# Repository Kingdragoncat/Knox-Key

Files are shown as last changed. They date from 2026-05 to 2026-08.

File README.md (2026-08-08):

# Knox Key

This is a custom USB-C FIDO2 security key. The repository contains the KiCad 9 hardware files (schematics, PCB layout, fab outputs) and the authenticator firmware. 

The hardware pairs an STM32L433 microcontroller with an ATECC608B secure element. The project started out as an STM32F072 design (originally named "kryptonite") but was later reworked to use the L433.

## Hardware Details
* **MCU:** STM32L433CB (LQFP-48) with an 8 MHz crystal and internal USB PHY.
* **Crypto:** ATECC608B secure element on I2C (PB6/PB7) for hardware TRNG.
* **Port:** USB Type-C running USB 2.0 full speed.
* **Feedback:** Single RGB LED. Green is success, red is error, blue/yellow indicates waiting for user presence.
* **Button:** Tactile button for user presence verification (supports single, double, and long presses).
* **Power:** USB bus-powered via a 3.3V MCP1700 LDO.
* **PCB:** 2-layer layout.

## Working with KiCad
Open `Knox Key Kicad.kicad_pro` in KiCad 9. Make sure to run ERC and DRC before exporting manufacturing outputs. If you are hand-assembling the board, open `bom/ibom.html` in a web browser for the interactive BOM.

## Firmware
The firmware is in `firmware/knoxkey/` and implements a FIDO2 / CTAP2 authenticator. Random numbers are pulled from the ATECC608B over I2C, while credential wrapping uses software AES. User presence is verified via the hardware button.

To build the target for the STM32L433:
```bash
cd firmware/knoxkey
cmake -B build/stm32l433-release -S . --preset default -DBUILD_TARGET=stm32l433
cmake --build build/stm32l433-release -j 8
```
Binaries (`.elf`, `.hex`, `.bin`) will compile into `build/stm32l433-release/targets/stm32l433/`. Flash them using an ST-Link or via USB DFU mode.

## Bill of Materials
17 line items, 29 components total. Machine-readable versions: [`BOM.csv`](BOM.csv) and [`BOM.md`](BOM.md). `manufacturing/bom.csv` has the same data in the exact format JLCPCB's assembly service expects.

| Designator | Qty | Value | Footprint | Description | LCSC Part # |
|---|---|---|---|---|---|
| C1, C11, C12 | 3 | 10u | 0603 | Bulk/decoupling capacitor | [C466781](https://www.lcsc.com/product-detail/C466781.html) |
| C10, C2, C3, C4, C5, C6, C7 | 7 | 100n | 0402 | Decoupling capacitor | [C6119799](https://www.lcsc.com/product-detail/C6119799.html) |
| C8, C9 | 2 | 33p | 0402 | Crystal load capacitor | [C696910](https://www.lcsc.com/product-detail/C696910.html) |
| D1 | 1 | ASMB-MTB1-0A3A2 | LED_Avago_PLCC4_3.2x2.8mm_CW | RGB status LED | — |
| J3 | 1 | Conn_01x05 | PinHeader_1x05_P2.54mm_Vertical | SWD debug header | — |
| P1 | 1 | USB_C_Plug_USB2.0 | TYPE-C-31-G-01 | USB Type-C receptacle | [C530605](https://www.lcsc.com/product-detail/C530605.html) |
| R1, R5 | 2 | 10k | 0402 | Pull-up resistor | [C60490](https://www.lcsc.com/product-detail/C60490.html) |
| R2, R3, R4 | 3 | 4k7 | 0402 | USB CC pull-down / series resistor | [C25940](https://www.lcsc.com/product-detail/C25940.html) |
| R6 | 1 | R* | 0402 | RGB LED red channel current-limiting resistor | — |
| R7 | 1 | G* | 0402 | RGB LED green channel current-limiting resistor | — |
| R8 | 1 | B* | 0402 | RGB LED blue channel current-limiting resistor | — |
| SW1 | 1 | SW_Push | SW_Push_1P1T_XKB_TS-1187A | User presence tactile button | [C318884](https://www.lcsc.com/product-detail/C318884.html) |
| U2 | 1 | ATECC608B-MAHDA | DFN-8-1EP_3x2mm_P0.5mm_EP1.3x1.5mm | Cryptographic secure element | [C1518773](https://www.lcsc.com/product-detail/C1518773.html) |
| U3 | 1 | MCP1700x-330xxTT | SOT-23 | 3.3V LDO regulator | [C39051](https://www.lcsc.com/product-detail/C39051.html) |
| U4 | 1 | USBLC6-2SC6 | SOT-23-6 | USB D+/D- ESD protection | [C7519](https://www.lcsc.com/product-detail/C7519.html) |
| U6 | 1 | STM32L433CBTx | LQFP-48_7x7mm_P0.5mm | Main microcontroller | — |
| Y1 | 1 | 8MHz | Crystal_SMD_3225-4Pin_3.2x2.5mm | Crystal oscillator | [C720915](https://www.lcsc.com/product-detail/C720915.html) |

\* R6/R7/R8 are still labeled with placeholder values (`R`/`G`/`B`) in the schematic rather than an actual resistance — confirm before ordering a board that needs them populated.

## Manufacturing & Ordering
All files needed to manufacture the board are inside `manufacturing/`:
* `gerbers/` and `knox-key-gerbers.zip` — Bare-board fabrication files.
* `bom.csv` — Bill of Materials (with LCSC part numbers).
* `positions.csv` — Pick-and-place component coordinates (CPL).
* `designators.csv` — Reference designator mappings.
* `netlist.ipc` — IPC-D-356 netlist.

For JLCPCB: Upload `knox-key-gerbers.zip` for the PCB, and use `bom.csv` and `positions.csv` for SMT assembly. Add a solder paste stencil to your order if you plan to solder manually. Don't forget to regenerate these from KiCad if you modify the layout!

## Renders
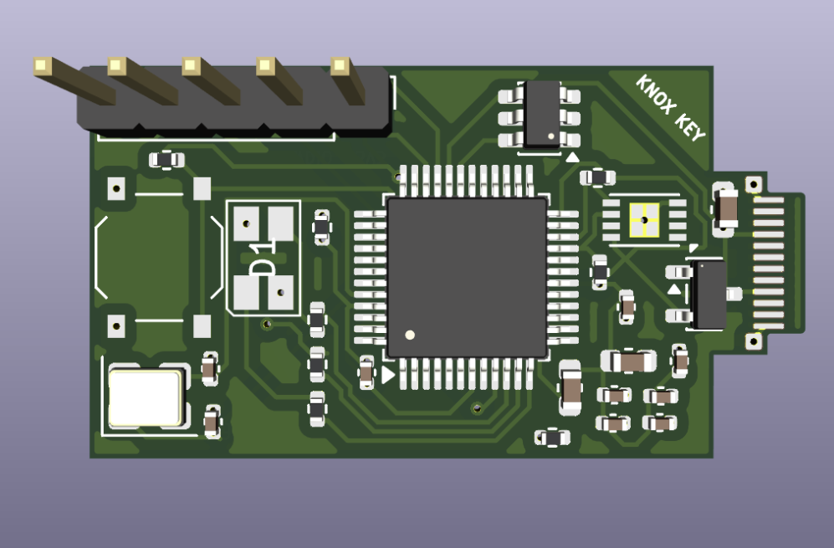
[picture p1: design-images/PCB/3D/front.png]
3D front

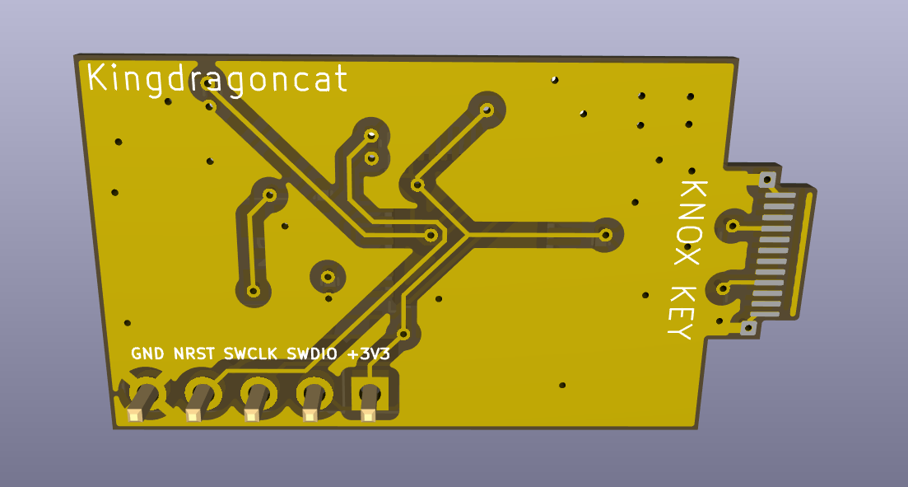
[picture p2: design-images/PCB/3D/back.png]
3D back

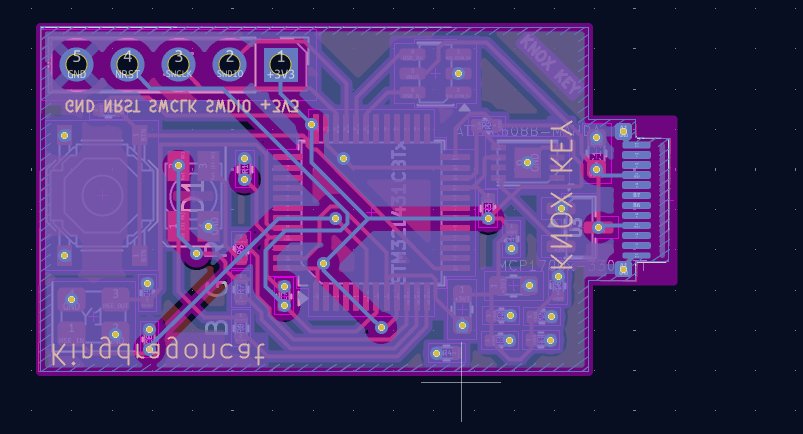
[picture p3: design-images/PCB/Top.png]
PCB layout

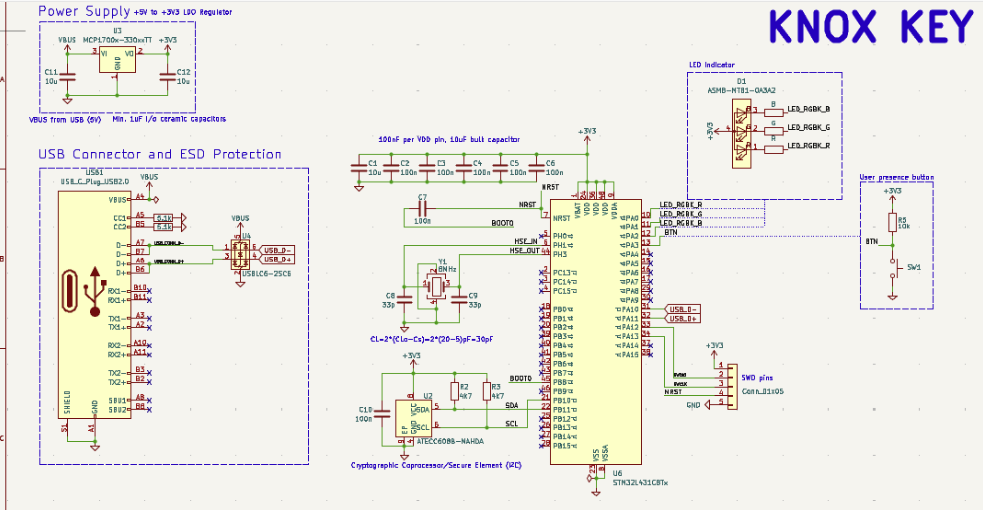
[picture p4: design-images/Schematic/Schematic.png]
Schematic


## Security Warning
This is a hobbyist project and has not undergone any formal security audit. The ATECC608B chips ship unprovisioned, meaning you must load your own keys onto the secure element. Do not use this for production environments without reviewing the firmware and provisioning process yourself.

## License
GPLv3. See `LICENSE` for details.

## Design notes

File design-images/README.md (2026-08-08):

design-images/

This folder holds two kinds of images, kept separate on purpose:

**Build journal screenshots** — flat files at the root of this folder, numbered `01`–`40` (e.g. `04_hkdf_code.png`, `21_schematic_full.png`). These are embedded chronologically in [`JOURNAL.md`](../JOURNAL.md) and shouldn't be renamed or moved; the journal links to them by exact filename.

**Current renders** — kept up to date with the latest hardware revision and embedded in the [Renders section of the README](../README.md#renders):
- `Schematic/Schematic.png` and `Schematic/schematic.pdf` — full schematic export.
- `PCB/Top.png`, `PCB/Bottom.png`, `PCB/NoFill.png`, `PCB/All.png` — 2D board layer views.
- `PCB/3D/front.png` and `PCB/3D/back.png` — 3D renders.

See [`CONTRIBUTING.md`](../CONTRIBUTING.md#how-to-update-renders) for how to regenerate the current renders after a layout change.

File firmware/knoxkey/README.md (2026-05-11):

# Knox Key Firmware

A high-security, hardware-backed FIDO2 (CTAP2) firmware implementation designed specifically for the Knox Key hardware.

## Features

- **Hardware-Backed Entropy**: All secure random numbers are generated using the onboard ATECC608B TRNG via I2C, meeting stringent security and FIPS compliance standards.
- **Hybrid Cryptography**: Leverages CryptoAuthLib for hardware random number generation while utilizing highly optimized software routines for ECDSA and AES-256 (for CTAP credential storage).
- **Advanced User Presence**: Features a fully-debounced hardware button detection engine supporting Single, Double, and Long clicks for various authentication actions.
- **Visual Feedback**: RGB LED states provide clear feedback on the authenticator's status:
  - **White Wink**: Device locator / ping
  - **Green**: Success / Validated Presence
  - **Red**: Error / Timeout / Cancelled
  - **Blue/Yellow**: Awaiting User Presence Heartbeat
- **Platform**: Ported to run efficiently on the STM32L433 MCU using TinyUSB for communication.

## Building the Firmware

### Requirements
- **CMake** (v3.20+)
- **Arm GNU Toolchain** (`arm-none-eabi-gcc`)
- **Make** / **Ninja** (depending on your OS)

### Instructions

1. **Clone the Repository**
   Make sure to clone with submodules to include all dependencies:
   ```bash
   git clone --recurse-submodules https://github.com/Kingdragoncat/Knox-Key.git
   cd "Knox-Key/Knox Key Kicad/firmware/knoxkey"
   ```

2. **Configure the Build System**
   ```bash
   cmake -B build/stm32l433-release -S . --preset default -DBUILD_TARGET=stm32l433
   ```

3. **Compile the Firmware**
   ```bash
   cmake --build build/stm32l433-release -j 8
   ```

4. **Flash the Microcontroller**
   The final compiled binaries (`.elf`, `.hex`, and `.bin`) will be output to:
   `build/stm32l433-release/targets/stm32l433/`
   
   You can flash the `.hex` or `.bin` file to your Knox Key via STM32CubeProgrammer over USB DFU mode, or using an ST-Link via SWD.

## Development & Porting

This firmware is a heavy modification of the original LionKey CTAP core. It has been extensively refactored to support the hardware components unique to the Knox Key design:
- STM32L433 target integration (USB, I2C, Flash Storage mapping)
- Replaced the software pseudo-random number generator with the ATECC608B hardware interface via `CryptoAuthLib`.
- Overhauled user-presence loops to leverage hardware interrupt-driven RGB LED multiplexing.

## License

This project is licensed under the GNU General Public License v3.0.

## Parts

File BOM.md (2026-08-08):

# Bill of Materials — Knox Key

17 line items, 29 components total. Machine-readable version: [`BOM.csv`](BOM.csv). This is also mirrored in `manufacturing/bom.csv`, which is the exact file used for JLCPCB SMT assembly ordering (see [Manufacturing & Ordering](README.md#manufacturing--ordering) in the README).

| Designator | Qty | Value | Footprint | Description | LCSC Part # |
|---|---|---|---|---|---|
| C1, C11, C12 | 3 | 10u | 0603 | Bulk/decoupling capacitor | [C466781](https://www.lcsc.com/product-detail/C466781.html) |
| C10, C2, C3, C4, C5, C6, C7 | 7 | 100n | 0402 | Decoupling capacitor | [C6119799](https://www.lcsc.com/product-detail/C6119799.html) |
| C8, C9 | 2 | 33p | 0402 | Crystal load capacitor | [C696910](https://www.lcsc.com/product-detail/C696910.html) |
| D1 | 1 | ASMB-MTB1-0A3A2 | LED_Avago_PLCC4_3.2x2.8mm_CW | RGB status LED | — |
| J3 | 1 | Conn_01x05 | PinHeader_1x05_P2.54mm_Vertical | SWD debug header | — |
| P1 | 1 | USB_C_Plug_USB2.0 | TYPE-C-31-G-01 | USB Type-C receptacle | [C530605](https://www.lcsc.com/product-detail/C530605.html) |
| R1, R5 | 2 | 10k | 0402 | Pull-up resistor | [C60490](https://www.lcsc.com/product-detail/C60490.html) |
| R2, R3, R4 | 3 | 4k7 | 0402 | USB CC pull-down / series resistor | [C25940](https://www.lcsc.com/product-detail/C25940.html) |
| R6 | 1 | R* | 0402 | RGB LED red channel current-limiting resistor | — |
| R7 | 1 | G* | 0402 | RGB LED green channel current-limiting resistor | — |
| R8 | 1 | B* | 0402 | RGB LED blue channel current-limiting resistor | — |
| SW1 | 1 | SW_Push | SW_Push_1P1T_XKB_TS-1187A | User presence tactile button | [C318884](https://www.lcsc.com/product-detail/C318884.html) |
| U2 | 1 | ATECC608B-MAHDA | DFN-8-1EP_3x2mm_P0.5mm_EP1.3x1.5mm | Cryptographic secure element | [C1518773](https://www.lcsc.com/product-detail/C1518773.html) |
| U3 | 1 | MCP1700x-330xxTT | SOT-23 | 3.3V LDO regulator | [C39051](https://www.lcsc.com/product-detail/C39051.html) |
| U4 | 1 | USBLC6-2SC6 | SOT-23-6 | USB D+/D- ESD protection | [C7519](https://www.lcsc.com/product-detail/C7519.html) |
| U6 | 1 | STM32L433CBTx | LQFP-48_7x7mm_P0.5mm | Main microcontroller | — |
| Y1 | 1 | 8MHz | Crystal_SMD_3225-4Pin_3.2x2.5mm | Crystal oscillator | [C720915](https://www.lcsc.com/product-detail/C720915.html) |

\* R6/R7/R8 (the RGB LED current-limiting resistors) are still labeled with placeholder values (`R`/`G`/`B`) in the schematic rather than an actual resistance — confirm and update before ordering a board that needs them populated.

Parts without an LCSC number (D1, J3, U6) aren't in JLCPCB's basic/extended parts library under that footprint/value combo and need to be hand-placed or sourced separately.

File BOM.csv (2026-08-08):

Designator | Quantity | Value | Footprint | Description | LCSC Part #
C1, C11, C12 | 3 | 10u | 0603 | Bulk/decoupling capacitor | C466781
C10, C2, C3, C4, C5, C6, C7 | 7 | 100n | 0402 | Decoupling capacitor | C6119799
C8, C9 | 2 | 33p | 0402 | Crystal load capacitor | C696910
D1 | 1 | ASMB-MTB1-0A3A2 | LED_Avago_PLCC4_3.2x2.8mm_CW | RGB status LED
J3 | 1 | Conn_01x05 | PinHeader_1x05_P2.54mm_Vertical | SWD debug header
P1 | 1 | USB_C_Plug_USB2.0 | TYPE-C-31-G-01 | USB Type-C receptacle | C530605
R1, R5 | 2 | 10k | 0402 | Pull-up resistor | C60490
R2, R3, R4 | 3 | 4k7 | 0402 | USB CC pull-down / series resistor | C25940
R6 | 1 | R* | 0402 | RGB LED red channel current-limiting resistor
R7 | 1 | G* | 0402 | RGB LED green channel current-limiting resistor
R8 | 1 | B* | 0402 | RGB LED blue channel current-limiting resistor
SW1 | 1 | SW_Push | SW_Push_1P1T_XKB_TS-1187A | User presence tactile button | C318884
U2 | 1 | ATECC608B-MAHDA | DFN-8-1EP_3x2mm_P0.5mm_EP1.3x1.5mm | Cryptographic secure element | C1518773
U3 | 1 | MCP1700x-330xxTT | SOT-23 | 3.3V LDO regulator | C39051
U4 | 1 | USBLC6-2SC6 | SOT-23-6 | USB D+/D- ESD protection | C7519
U6 | 1 | STM32L433CBTx | LQFP-48_7x7mm_P0.5mm | Main microcontroller
Y1 | 1 | 8MHz | Crystal_SMD_3225-4Pin_3.2x2.5mm | Crystal oscillator | C720915

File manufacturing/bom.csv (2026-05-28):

Designator | Footprint | Quantity | Value | LCSC Part #
C1, C11, C12 | 0603 | 3 | 10u | C466781
C10, C2, C3, C4, C5, C6, C7 | 0402 | 7 | 100n | C6119799
C8, C9 | 0402 | 2 | 33p | C696910
D1 | LED_Avago_PLCC4_3.2x2.8mm_CW | 1 | ASMB-MTB1-0A3A2
J3 | PinHeader_1x05_P2.54mm_Vertical | 1 | Conn_01x05
P1 | TYPE-C-31-G-01 | 1 | USB_C_Plug_USB2.0 | C530605
R1, R5 | 0402 | 2 | 10k | C60490
R2, R3, R4 | 0402 | 3 | 4k7 | C25940
R6 | 0402 | 1 | R
R7 | 0402 | 1 | G
R8 | 0402 | 1 | B
SW1 | SW_Push_1P1T_XKB_TS-1187A | 1 | SW_Push | C318884
U2 | DFN-8-1EP_3x2mm_P0.5mm_EP1.3x1.5mm | 1 | ATECC608B-MAHDA | C1518773
U3 | SOT-23 | 1 | MCP1700x-330xxTT | C39051
U4 | SOT-23-6 | 1 | USBLC6-2SC6 | C7519
U6 | LQFP-48_7x7mm_P0.5mm | 1 | STM32L433CBTx
Y1 | Crystal_SMD_3225-4Pin_3.2x2.5mm | 1 | 8MHz | C720915

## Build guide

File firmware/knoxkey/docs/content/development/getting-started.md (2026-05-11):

---
sidebar_position: 1
---

# Getting Started

Set up development environment, build the sources, and run LionKey.

## Requirements

- [CMake] _(tested with version 3.30.5)_
  - Note: [CLion](#using-ide) has a bundled CMake so there is no need to install it.

- [Arm GNU Toolchain] _(tested with Version 14.2.Rel1)_
  - Download _AArch32 bare-metal target (arm-none-eabi)_ from the Arm website [here][Arm GNU Toolchain].
  - On macOS, `brew install --cask gcc-arm-embedded` can be used.

- [OpenOCD] or any other tool for programming and debugging Arm Cortex-M microcontrollers,
  such as pyOCD or ST-LINK_gdbserver (a part of STM32CubeIDE).

  :::danger[Caution]

  **STM32H5** does not work with the original OpenOCD.
  Currently, it only works with the STMicroelectronics' fork [STMicroelectronics/OpenOCD],
  which has to be built from source, **see 👉 [this guide for the instructions](./openocd)**

  :::

## Cloning the Project

The project uses [Git submodules] to manage some of the external dependencies (see [.gitmodules](https://github.com/pokusew/lionkey/blob/main/.gitmodules)).

There are two options how to get the contents of the submodules:

**When cloning the project**, you can use:

```bash
git clone --recurse-submodules https://github.com/pokusew/lionkey.git
```

**If you already cloned the project** and forgot `--recurse-submodules`, you can use:

```bash
git submodule update --init --recursive
```

## Build from the Command Line

It is possible to build, flash and start the whole project from the command line.

Building is done via `cmake` since this project is a standard [CMake] project (see [CMakeLists.txt](https://github.com/pokusew/lionkey/blob/main/CMakeLists.txt)).
We also included a [CMakePresets.json](https://github.com/pokusew/lionkey/blob/main/CMakePresets.json) to simplify passing common options.

Here is an example how to build the executable for the NUCLEO-H533RE board with the STM32H533RET6 MCU.

```bash
# configure step (only has to be done once)
cmake --preset stm32h533-debug
# build step
cmake --build --preset stm32h533-debug
```

Flashing can be done for example using `openocd` like this (run from the project root):

```bash
openocd -s /usr/local/share/openocd/scripts -f targets/stm32h533/st_nucleo_h5.cfg -c 'tcl_port disabled' -c 'gdb_port disabled' -c 'program "build/stm32h533-debug/targets/stm32h533/lionkey_stm32h533.elf"' -c reset -c shutdown
```

## Using IDE

**Use JetBrains [CLion] (free for non-commercial use) for development.**
The project is already imported and fully configured, use _File > Open..._ to just open it.

If you have all the [tools](#requirements) installed, you should be able to open, build and run the project from CLion.

You can read more in this [CLion's Embedded development with STM32CubeMX projects][CLion-Embedded-Development]
guide.

Note that CLion bundles CMake (and other tools). Those can be used outside CLion from terminal as well.
On a x64 macOS system, the CLion's `cmake` binary
is located at `/Applications/CLion.app/Contents/bin/cmake/mac/x64/bin/cmake`.
If you add the `/Applications/CLion.app/Contents/bin/cmake/mac/x64/bin/` dir to your PATH,
then you can run CLion's CMake just by typing `cmake` in your terminal.

## SVD file for the MCU

CLion and other IDEs support SVD files for describing the layout of registers for debugging.

See the [README in the tools/svd dir](https://github.com/pokusew/lionkey/blob/main/tools/svd/README.md) which lists the available SVD files you can use.

<!-- links references -->

[Thesis]: https://github.com/pokusew/fel-masters-thesis
[Thesis-PDF]: https://github.com/pokusew/fel-masters-thesis/raw/main/docs/FIDO2_USB_Security_Key.pdf
[FIDO2]: https://fidoalliance.org/specifications/
[WebAuthn]: https://w3c.github.io/webauthn/
[CTAP 2.1]: https://fidoalliance.org/specs/fido-v2.1-ps-20210615/fido-client-to-authenticator-protocol-v2.1-ps-errata-20220621.html
[TinyCBOR]: https://github.com/intel/tinycbor
[NUCLEO-H533RE]: https://www.st.com/en/evaluation-tools/nucleo-h533re.html
[STM32H533RET6]: https://www.st.com/en/microcontrollers-microprocessors/stm32h533re.html
[STM32CubeH5-GitHub]: https://github.com/STMicroelectronics/STM32CubeH5
[STM32CubeH5-Product-Page]: https://www.st.com/en/embedded-software/stm32cubeh5.html#documentation
[UM3132]: https://www.st.com/resource/en/user_manual/um3132-description-of-stm32h5-hal-and-lowlayer-drivers-stmicroelectronics.pdf
[STM32CubeMX]: https://www.st.com/en/development-tools/stm32cubemx.html
[CLion]: https://www.jetbrains.com/clion/
[CLion-Embedded-Development]: https://www.jetbrains.com/help/clion/embedded-development.html
[Arm GNU Toolchain]: https://developer.arm.com/downloads/-/arm-gnu-toolchain-downloads
[OpenOCD]: https://openocd.org/pages/getting-openocd.html
[STMicroelectronics/OpenOCD]: https://github.com/STMicroelectronics/OpenOCD
[xPack OpenOCD Releases]: https://github.com/xpack-dev-tools/openocd-xpack/releases
[CMake]: https://cmake.org/
[Git submodules]: https://git-scm.com/docs/gitsubmodules

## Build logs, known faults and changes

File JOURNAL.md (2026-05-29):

---
title: "Knox Key"
author: "Kingdragoncat"
description: "A high-security USB Type-C authentication key design built with KiCad 8, featuring the ATECC608B cryptographic authentication chip and secure firmware validation mechanisms."
created_at: "2026-03-10"
---

# March 10, 2026: Project Initiation & Hardware Security Research

I decided to build my own hardware FIDO2 security key. I started by researching how hardware security keys actually work, reading up on FIDO2, U2F standards, and comparing existing commercial devices like YubiKeys and Titan keys. I got inspired after doing a talk on security keys to build one myself.

Next, I looked at open-source FIDO2 key implementations. I did a deep dive into the Lionkey project, analyzing their schematics, component choices, and repository structure. This gave me a good reference model.

With a general design in mind, I initialized the KiCad project and began searching for MCU options. I checked JLCPCB's assembly catalog for parts with USB device stacks and sufficient RAM/Flash for cryptographic operations. I compared STM32F072, STM32L433, and similar models, ultimately choosing the STM32F072 as the main MCU due to its excellent FIDO2 support, cost, and availability.

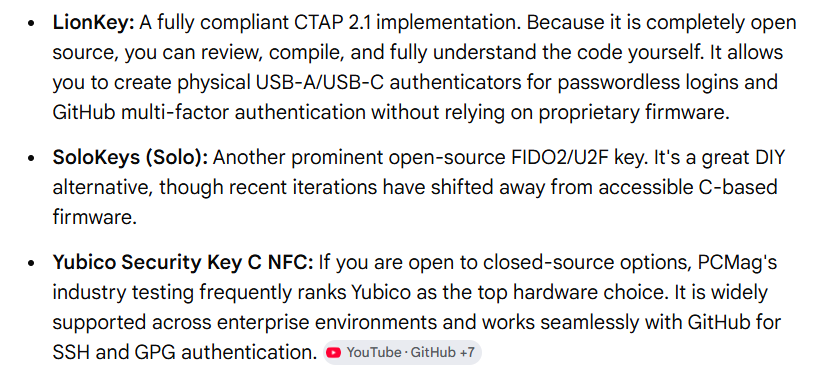
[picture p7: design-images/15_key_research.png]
Key Research

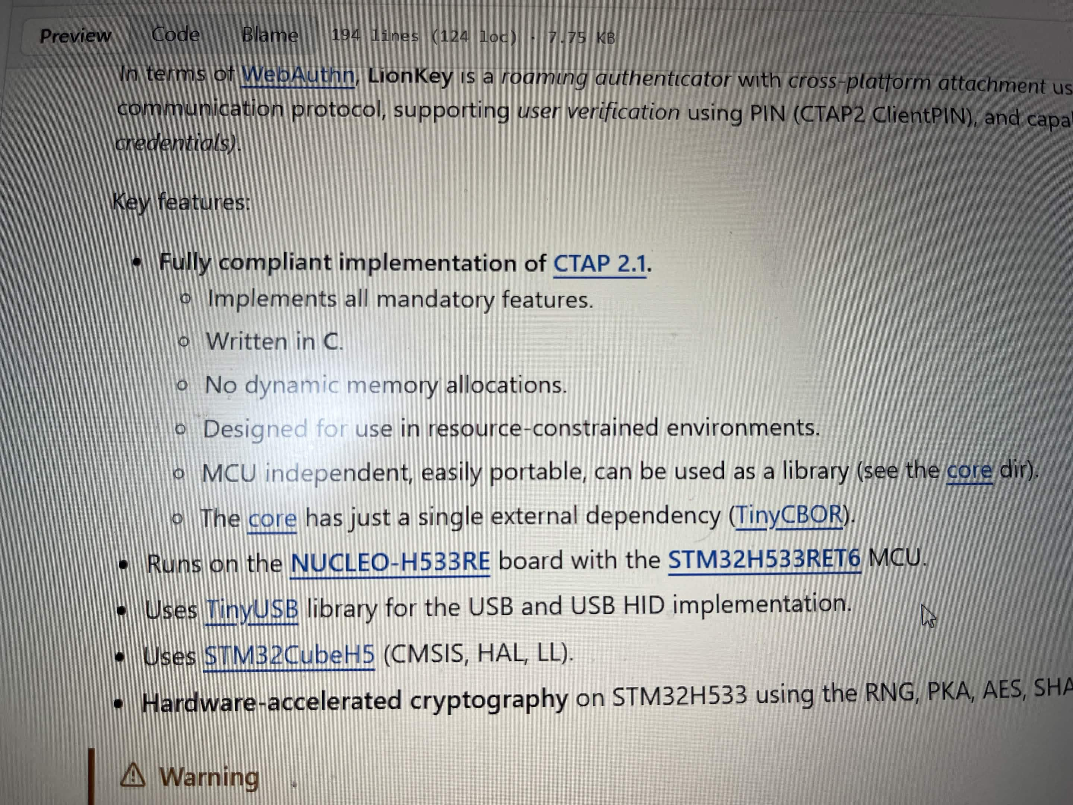
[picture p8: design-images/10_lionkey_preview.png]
LionKey reference

Start Project
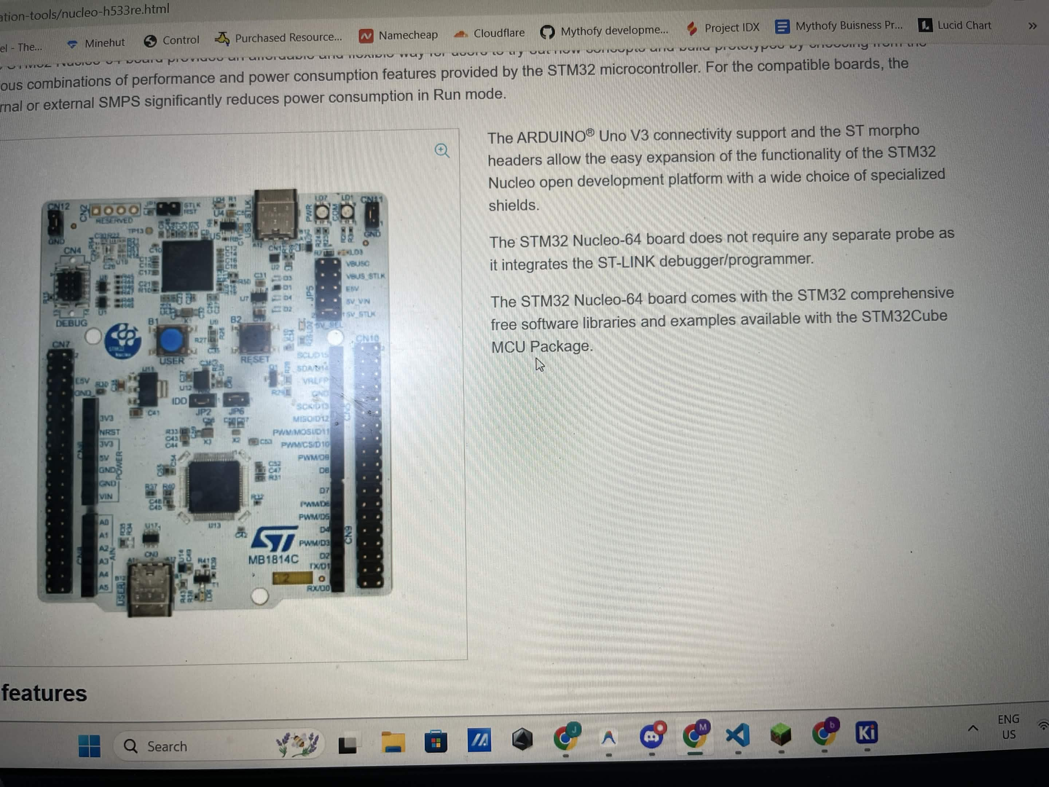
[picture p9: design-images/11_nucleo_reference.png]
Nucleo reference

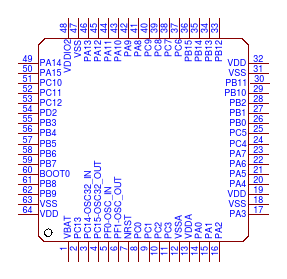
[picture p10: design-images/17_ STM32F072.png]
STM32F072 MCU


Total time spent: 3 hours

# March 12, 2026: Component Selection & BOM Generation

With the MCU selected, I focused on choosing the rest of the bill of materials. I searched JLCPCB for voltage regulators capable of producing a stable 3.3V rail from the 5V USB line, selecting the MCP1700T-3302E in a compact SOT-23 package and noting its recommended decoupling capacitor configuration.

For hardware cryptography, I picked the ATECC608 cryptographic coprocessor from Microchip. This handles ECDSA signatures and other FIDO2 operations securely. I then selected a Type-C connector and the USBLC6-2SC6 ESD protection chip for the data lines. Finally, I gathered passive component packages (resistors, decoupling capacitors, and pull-ups) to ensure everything was single-side mountable for easier assembly, and ran the KiCad BOM export plugin to generate our clean BOM file.

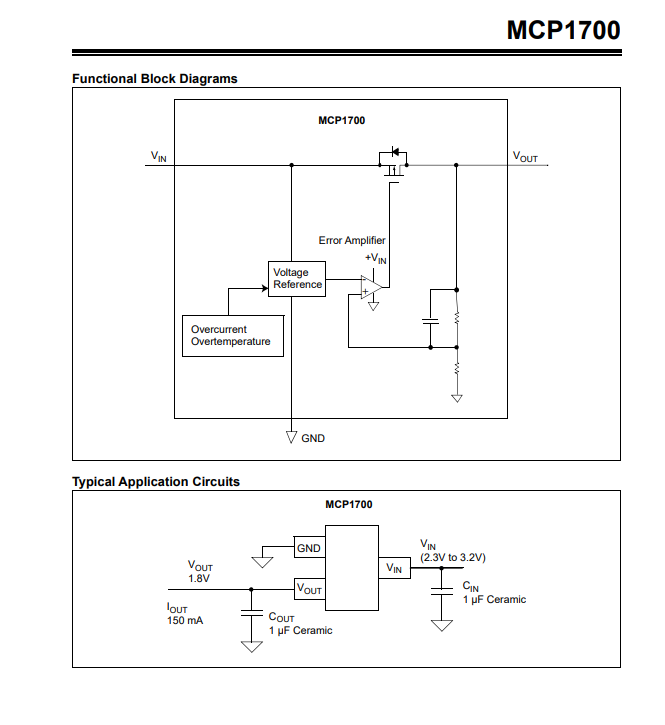
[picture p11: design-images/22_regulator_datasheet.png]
Regulator selection

ATECC608 selection
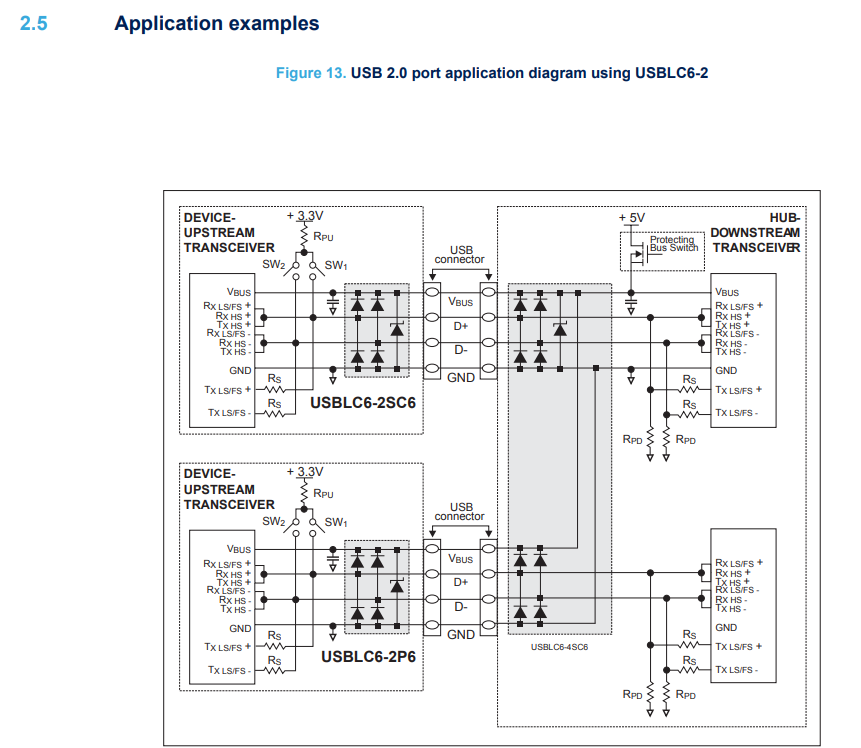
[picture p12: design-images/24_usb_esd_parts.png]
USB and ESD parts

Passives selection
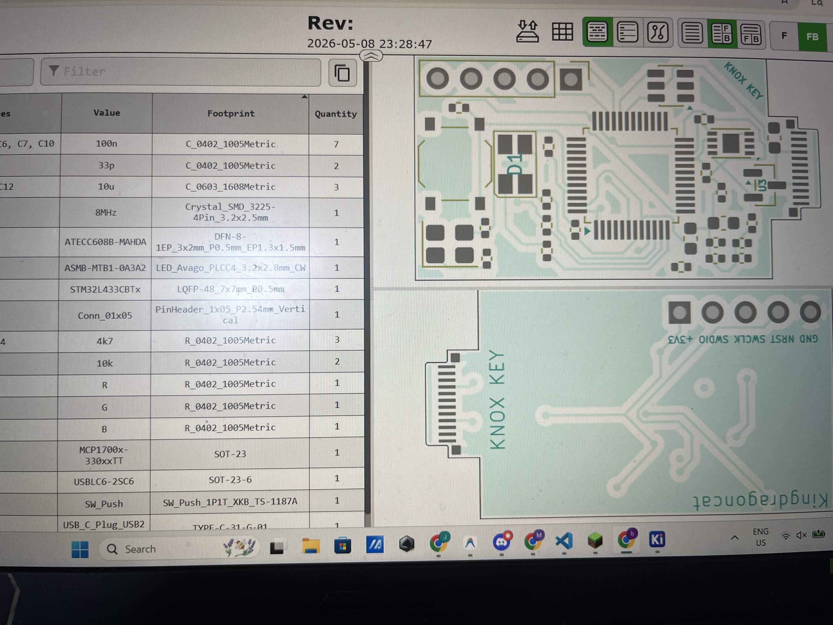
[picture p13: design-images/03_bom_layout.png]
BOM generation


Total time spent: 2 hours

# March 15, 2026: Drawing Main Power, USB, and MCU Connections

I started drafting the schematic in KiCad, beginning with the main power supply circuits. I placed the voltage regulator, its input/output decoupling capacitors, and set up the power bus.

Next, I wired up the USB Type-C connector. I configured the CC pins with 5.1k pull-down resistors to enable proper host detection, set up series impedance matching resistors on the D+/D- lines, and integrated the ESD protection chip. Finally, I added the STM32F072 microcontroller, wiring up its power pins, crystal oscillator, and local decoupling caps, making sure they were grouped logically near the MCU pins.

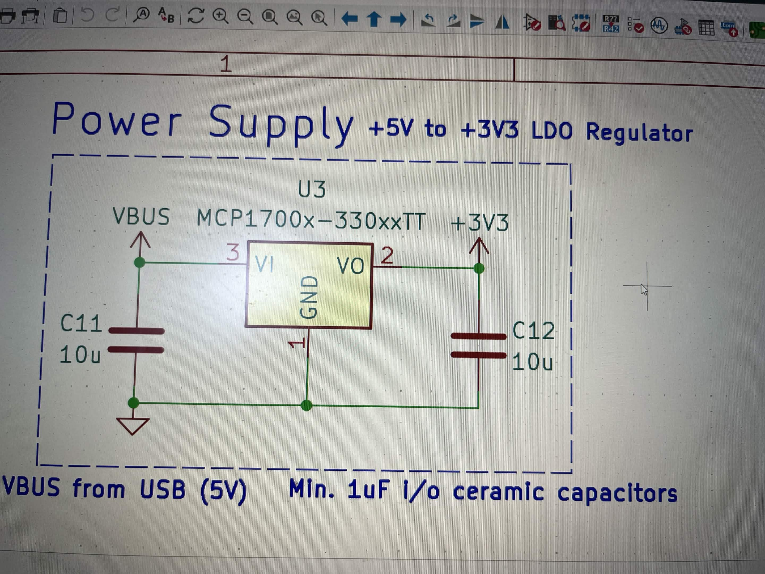
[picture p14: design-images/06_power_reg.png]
Power schematic

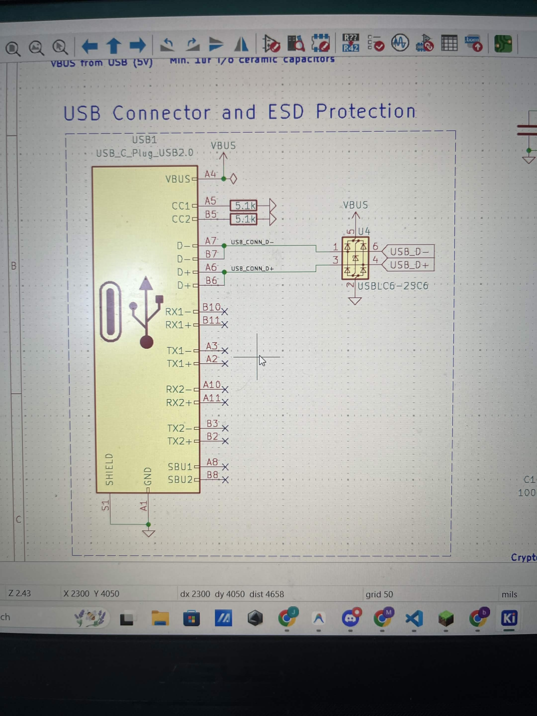
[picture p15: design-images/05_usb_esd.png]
USB ESD schematic

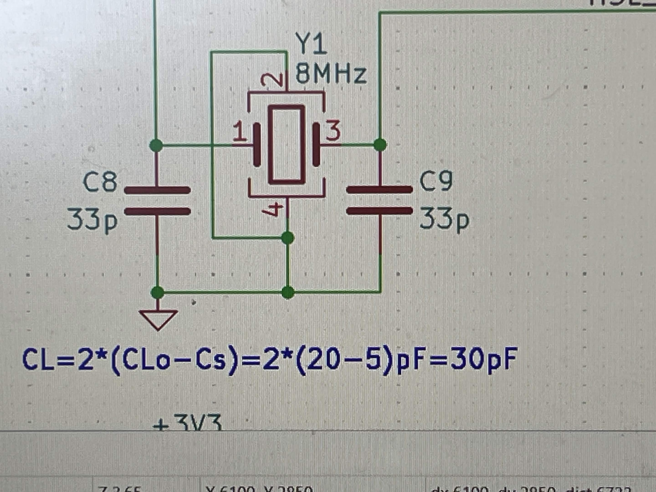
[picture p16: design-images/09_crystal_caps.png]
Crystal oscillator schematic


Total time spent: 4.5 hours

# March 18, 2026: Crypto Chip integration, Debug Ports, and ERC Checks

I completed the remaining parts of the schematic. First, I placed the ATECC608 crypto coprocessor and connected its I2C bus (SDA and SCL lines) directly to the MCU, including pull-up resistors and a dedicated decoupling capacitor.

To make testing possible, I added an SWD debug header, connecting the SWDIO and SWCLK lines. I also added a status indicator RGB LED with appropriate series current-limiting resistors, as well as a tactile button for user presence detection. Once the design was fully wired, I cleaned up the layout, routed sheet symbols, and ran the Electrical Rules Checker (ERC), correcting a couple of missing pin connections.

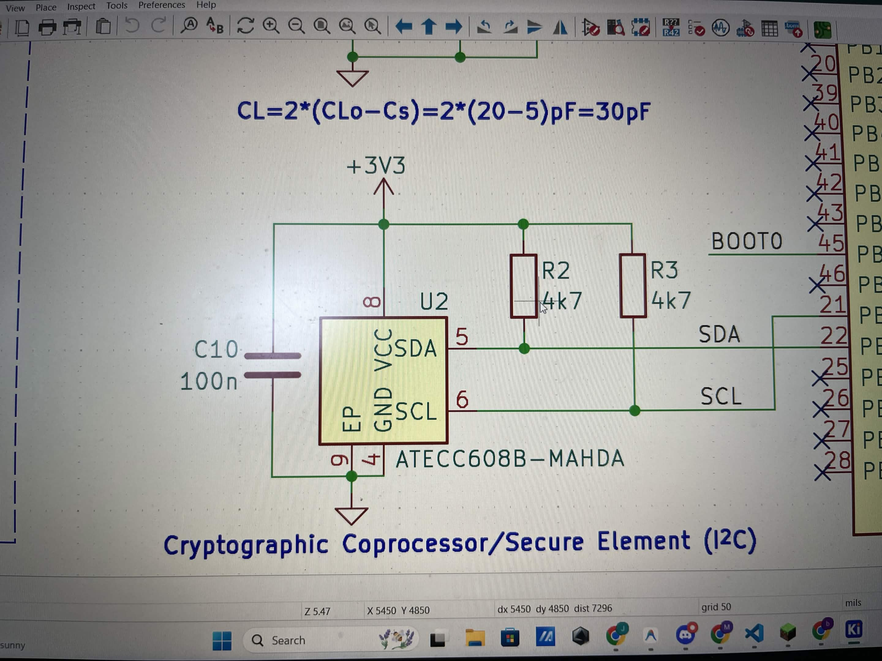
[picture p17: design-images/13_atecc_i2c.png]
ATECC608 I2C schematic

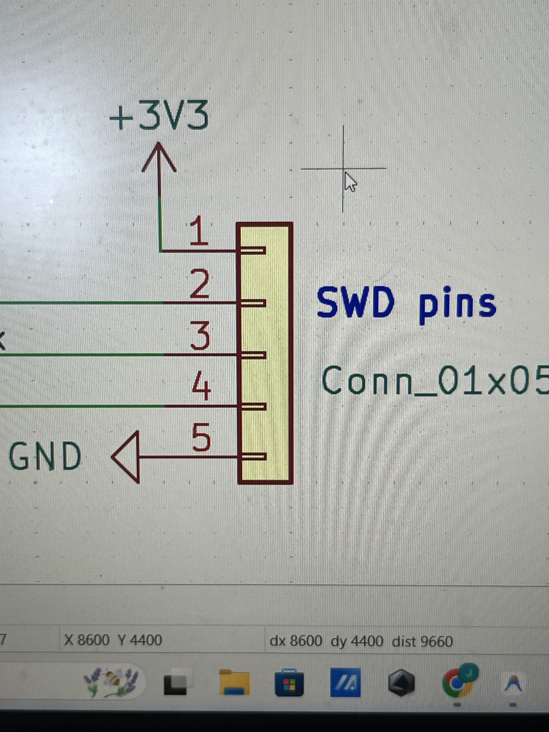
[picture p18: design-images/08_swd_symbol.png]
SWD port schematic

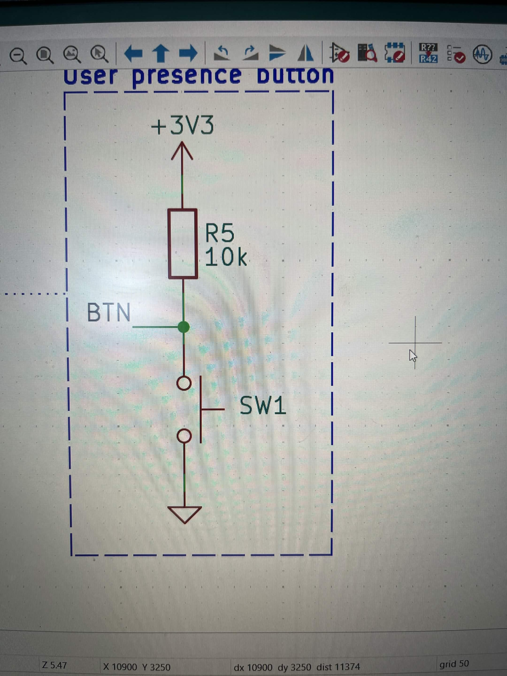
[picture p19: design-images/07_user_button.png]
User button and LED schematic

Full schematic
ERC check report

Total time spent: 2.25 hours

# March 22, 2026: PCB Placement & Critical Trace Routing

With a clean schematic, I imported the netlist into the PCB Editor. I spent a long time arranging the components to minimize the board's footprint, placing the USB Type-C connector on the edge, the MCU in the center, and the crypto chip and passives in compact clusters.

Once the layout was solid, I routed the copper traces. I prioritized the critical USB differential pair, ensuring the D+ and D- lines were routed with matched lengths and controlled impedance. I kept these high-speed lines away from noisier components and routing paths, making multiple optimization passes to keep trace lengths short.

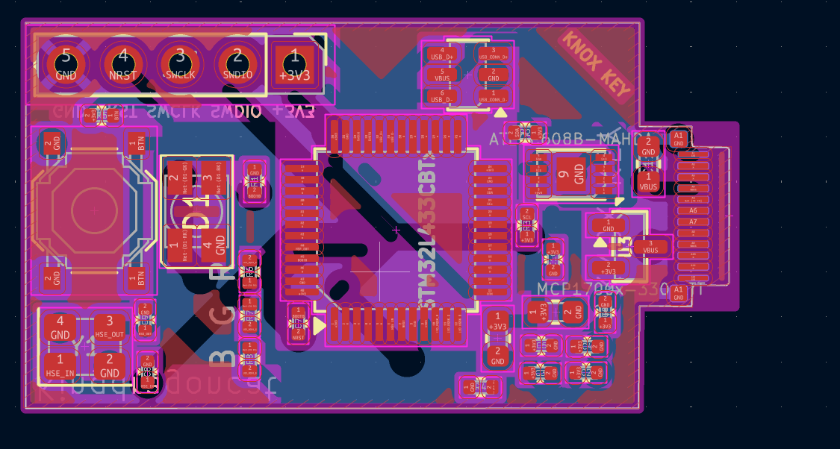
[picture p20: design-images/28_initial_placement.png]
PCB placement

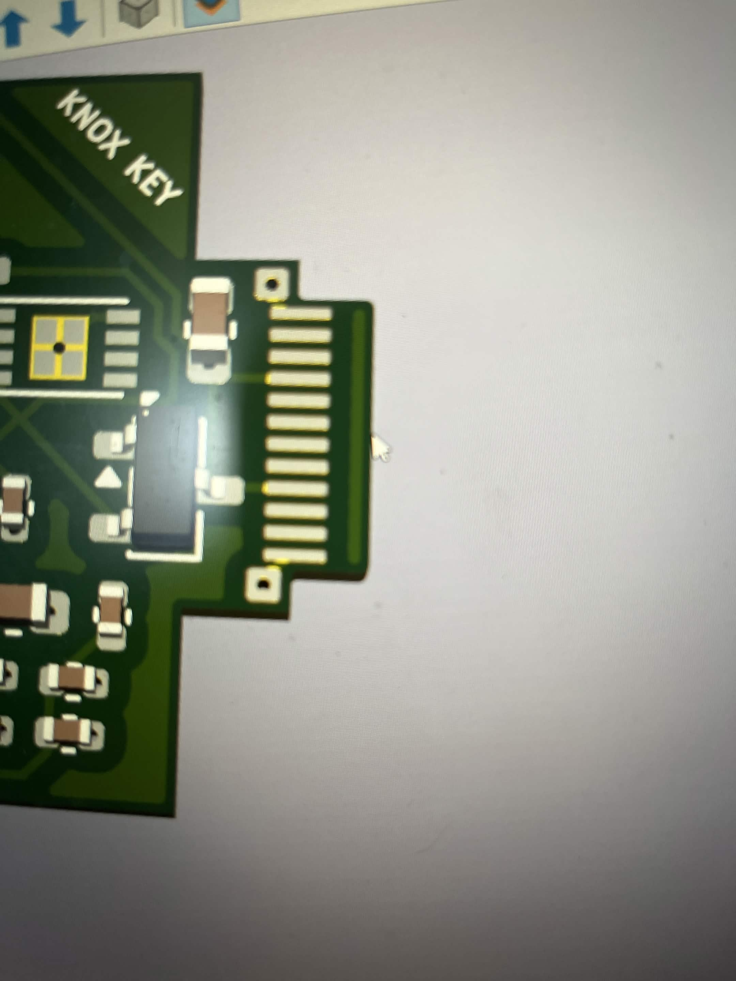
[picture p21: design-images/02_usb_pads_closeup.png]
USB trace routing


Total time spent: 6.5 hours

# March 25, 2026: Ground Pouring & Design Rule Checks

I worked on improving noise immunity and power distribution. First, I added copper ground planes to the top and bottom layers of the board, along with 3.3V power rails to distribute current cleanly. 

To improve performance, I replaced my original discrete wired ground connections with a unified ground pour/splash. Removing the old ground traces and stitching the planes together with vias took about 40 minutes. Finally, I ran the Design Rules Checker (DRC), correcting a few spacing violations and narrow trace segments.

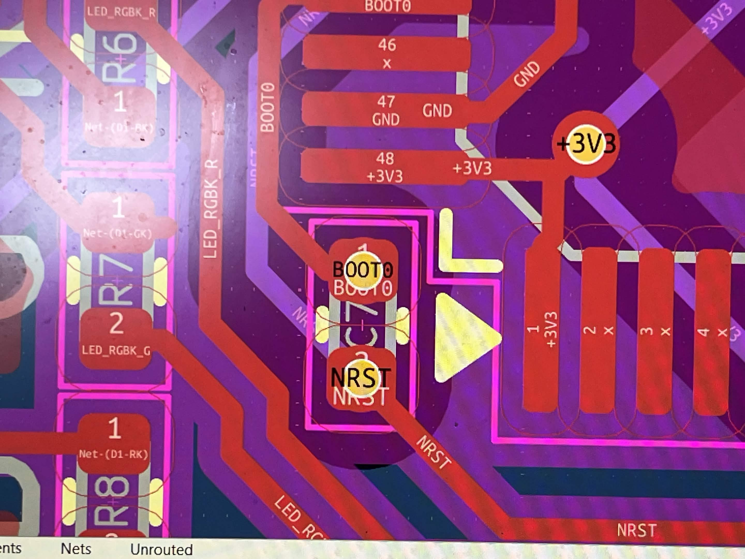
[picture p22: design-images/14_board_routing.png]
Board trace views

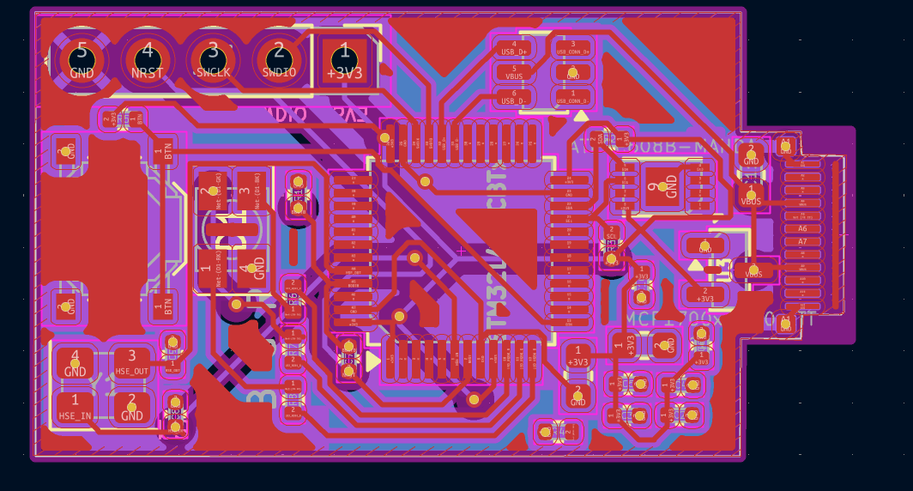
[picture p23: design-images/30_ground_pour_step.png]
Ground pour

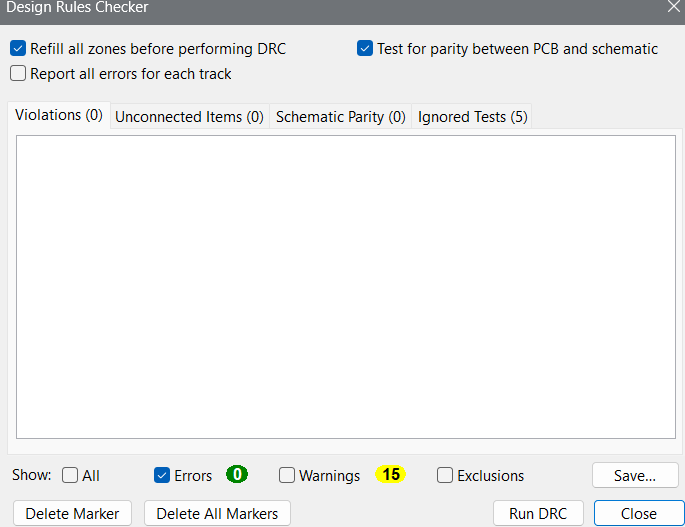
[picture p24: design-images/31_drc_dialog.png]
DRC check report


Total time spent: 3.2 hours

# March 28, 2026: Modifying USB Connector and Crash Recovery

I attempted to modify the USB Type-C connector to a more robust version with a metal shell for extra durability. This required changing the schematic symbol, switching the footprint, and rerouting the critical USB data lines. 

Halfway through the layout rework, KiCad crashed unexpectedly. I lost about 30 minutes of work because of the crash. Luckily, I was able to recover most of it from the automatic backups in my project folder. I restored the project, re-completed the PCB modifications, and fixed the DRC clearance issues again.

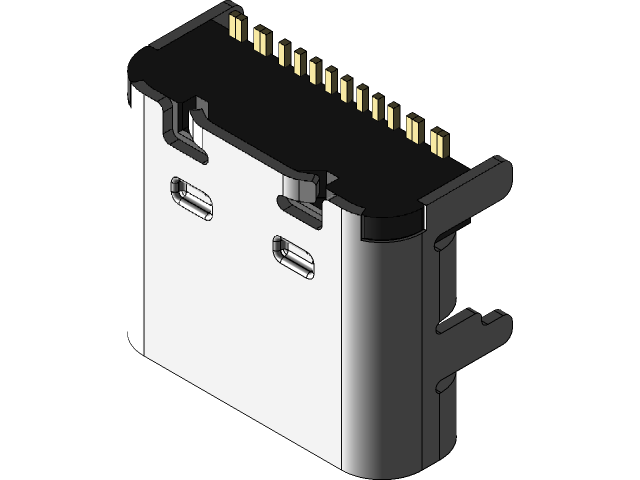
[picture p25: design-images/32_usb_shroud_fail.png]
USB footprint rework

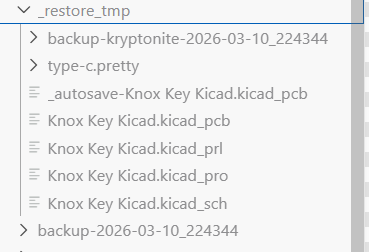
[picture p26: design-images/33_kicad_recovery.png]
KiCad recovery folder

PCB layout state

Total time spent: 4 hours

# April 02, 2026: Simplification, Slack Feedback, & Manufacturing Prep

After reviewing the complex metal-shrouded connector, I realized it added unnecessary complexity and routing congestion. I decided to revert to the original, simpler USB Type-C design. 

I posted the design on the Hack Club Slack to get feedback. Someone pointed out that the RGB LED was wired to GND instead of 3.3V, so I corrected the schematic and rerouted that section. I then exported our production-ready Gerber files, drill files, and component placement coordinates (CPL). I did a final check using the 3D viewer to make sure component clearances and alignments looked correct.

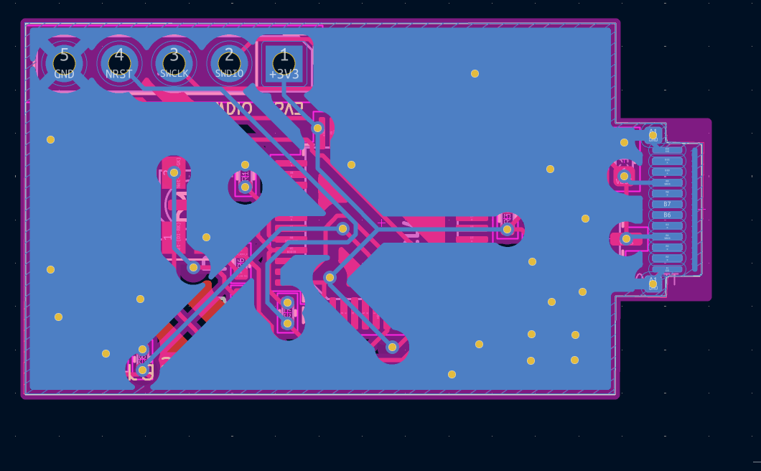
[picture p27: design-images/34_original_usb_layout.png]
Reverted USB layout

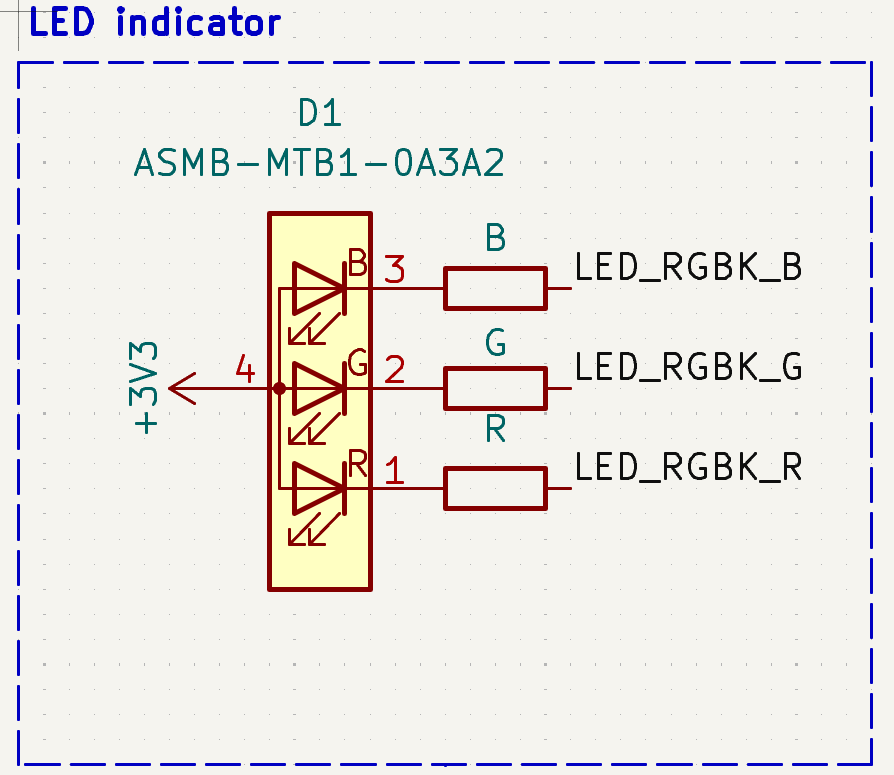
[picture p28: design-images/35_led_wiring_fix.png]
LED wiring fix

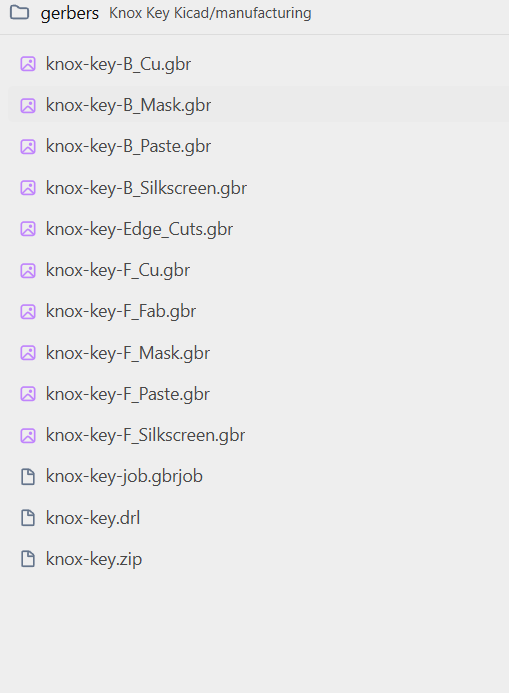
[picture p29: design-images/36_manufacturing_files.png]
Generated gerbers list

3D model check

Total time spent: 3.5 hours

# April 10, 2026: Firmware Build System & USB Setup

With the hardware finalized, I transitioned to software. I set up the firmware build environment using CMake and the `arm-none-eabi-gcc` toolchain. I configured the build settings for the ARM Cortex-M0 core and defined the compiler flags and linker script mappings.

Once the build system compiled successfully, I configured the STM32 HAL USB device stack. I defined the basic USB descriptors, set up endpoint configurations, and confirmed that the device successfully enumerated on my PC as an unrecognized USB device.

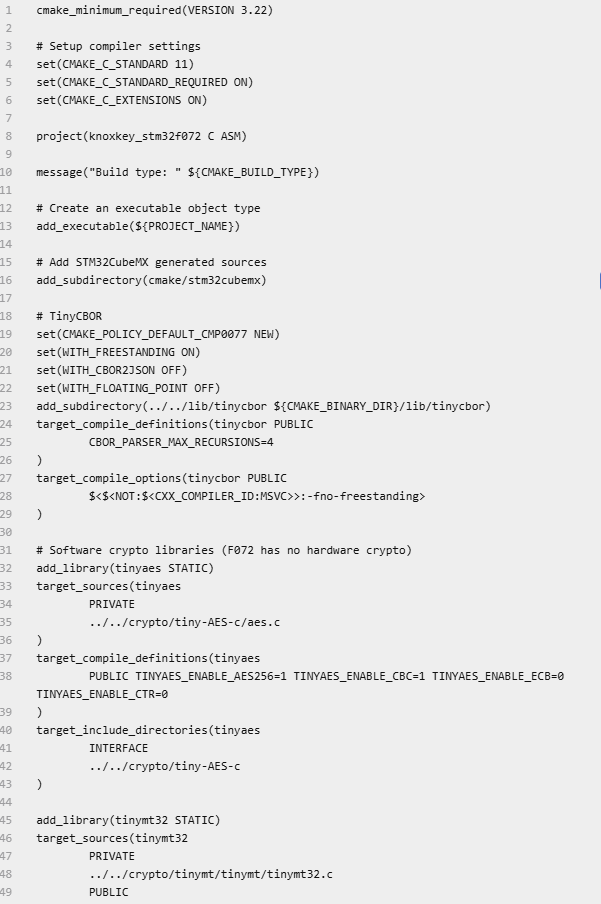
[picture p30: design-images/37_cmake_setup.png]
CMake setup

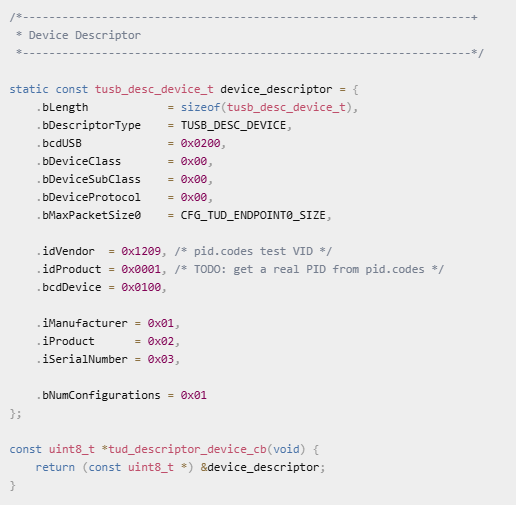
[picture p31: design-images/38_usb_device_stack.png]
USB stack setup


Total time spent: 2.5 hours

# April 15, 2026: Implementing FIDO2 & Command Parsing

I began implementing the FIDO2 protocol layer. I set up the USB Human Interface Device (HID) descriptors so the key could communicate with the host operating system. I also implemented key derivation logic utilizing HKDF for security.

Finally, I wrote the basic packet parsing state machine. This extracts incoming FIDO2 command packets from raw USB HID reports and routes them to the appropriate handler functions. The key can now parse packets and prepare response packets to send back to the computer.

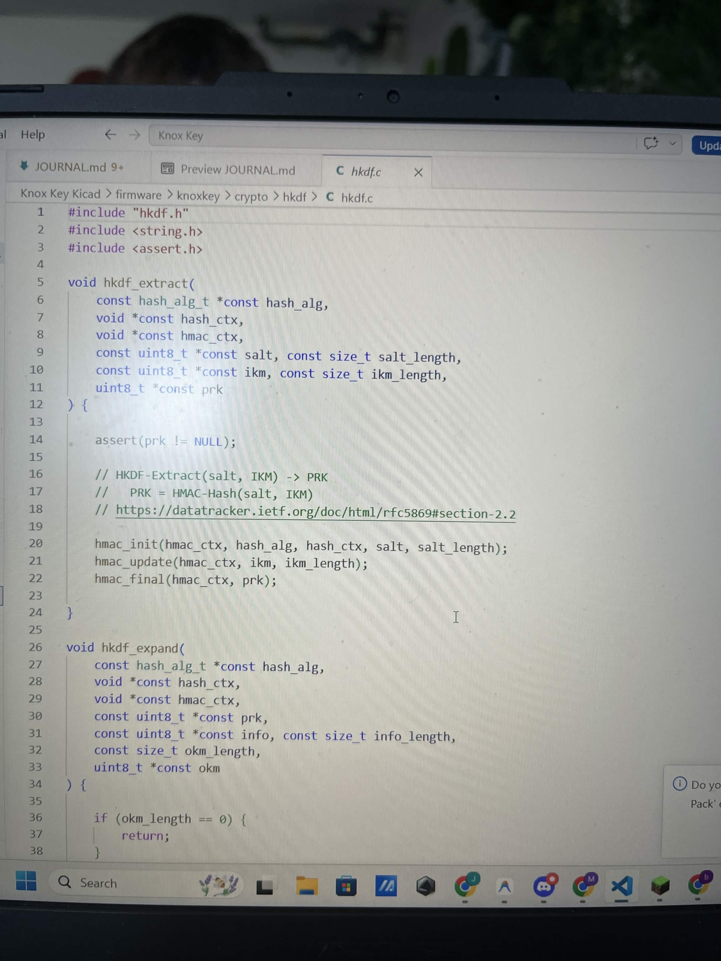
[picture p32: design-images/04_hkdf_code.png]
FIDO2 HKDF implementation

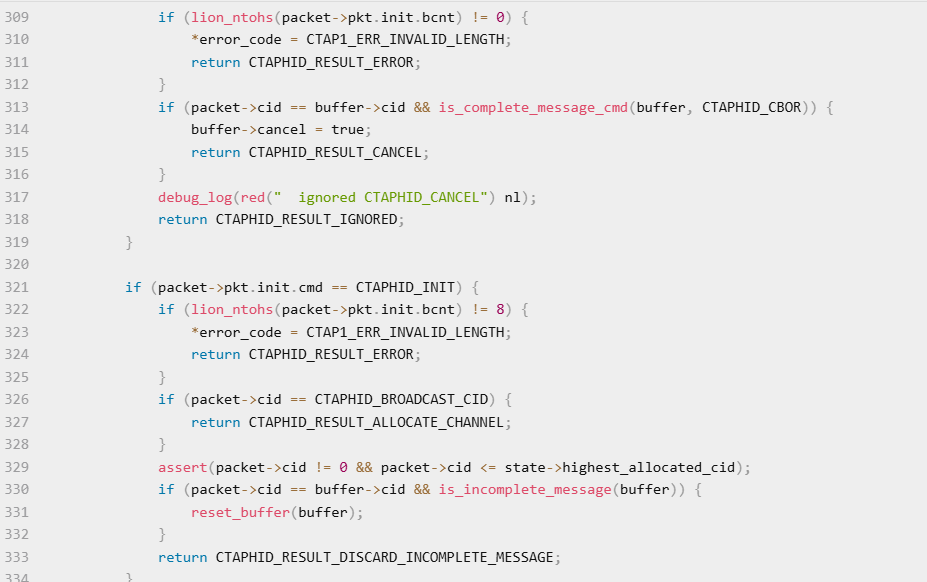
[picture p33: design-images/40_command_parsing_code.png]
Command parsing code


Total time spent: 1.25 hours

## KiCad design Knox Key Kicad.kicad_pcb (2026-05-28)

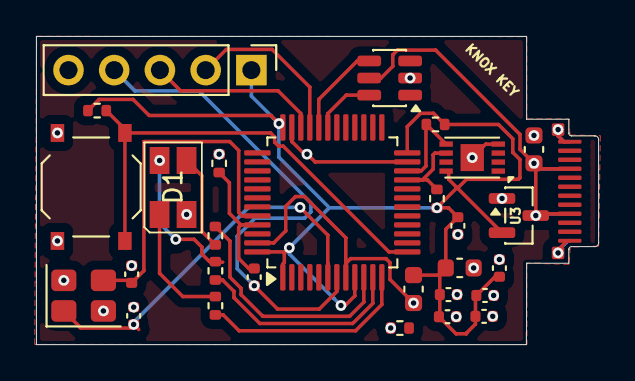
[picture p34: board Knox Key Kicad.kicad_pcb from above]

Board: 2 copper layers, 31.2 x 17.1 mm, 29 parts (0 on the bottom side), 20 nets.

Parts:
C1, C11, C12: 10u; C_0603_1608Metric
C2, C3, C4, C5, C6, C7, C10: 100n; C_0402_1005Metric
C8, C9: 33p; C_0402_1005Metric
D1: ASMB-MTB1-0A3A2; LED_Avago_PLCC4_3.2x2.8mm_CW
J3: Conn_01x05; PinHeader_1x05_P2.54mm_Vertical
P1: USB_C_Plug_USB2.0; TYPE-C-31-G-01
R1, R5: 10k; R_0402_1005Metric
R2, R3, R4: 4k7; R_0402_1005Metric
R6: R; R_0402_1005Metric
R7: G; R_0402_1005Metric
R8: B; R_0402_1005Metric
SW1: SW_Push; SW_Push_1P1T_XKB_TS-1187A
U2: ATECC608B-MAHDA; DFN-8-1EP_3x2mm_P0.5mm_EP1.3x1.5mm
U3: MCP1700x-330xxTT; SOT-23
U4: USBLC6-2SC6; SOT-23-6
U6: STM32L433CBTx; LQFP-48_7x7mm_P0.5mm
Y1: 8MHz; Crystal_SMD_3225-4Pin_3.2x2.5mm

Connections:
+3V3: C1.1, C2.1, C3.1, C4.1, C5.1, C6.1, C10.1, C12.1, J3.1, R2.1, R3.1, R5.2, U2.8 (VCC), U3.2 (VO), U6.1 (VBAT), U6.9 (VDDA), U6.24 (VDD), U6.36 (VDD), U6.48 (VDD)
/BOOT0: C7.1, R1.2, U6.45 (PB8)
/BTN: R5.1, SW1.1, U6.13 (PA3)
/HSE_IN: C8.1, U6.6 (PH1), Y1.1
/HSE_OUT: C9.1, U6.44 (PH3), Y1.3
/LED_RGBK_B: R8.2, U6.12 (PA2)
/LED_RGBK_G: R7.2, U6.11 (PA1)
/LED_RGBK_R: R6.2, U6.10 (PA0)
/NRST: C7.2, J3.4, U6.7 (NRST)
/SCL: R3.2, U2.6 (SCL), U6.21 (PB10)
/SDA: R2.2, U2.5 (SDA), U6.22 (PB11)
/SWCLK: J3.3, U6.34 (PA13)
/SWDIO: J3.2, U6.33 (PA12)
GND: C1.2, C2.2, C3.2, C4.2, C5.2, C6.2, C8.2, C9.2, C10.2, C11.2, C12.2, D1.4 (A), J3.5, P1.A1 (GND), P1.A12 (GND), P1.B1 (GND), P1.B12 (GND), R1.1, R4.1, SW1.2, U2.4 (GND), U2.9 (EP), U3.1 (GND), U4.2 (GND), U6.8 (VSSA), U6.23 (VSS), U6.35 (VSS), U6.47 (VSS), Y1.2, Y1.4
unnamed: D1.3 (BK), R6.1
unnamed: D1.2 (GK), R7.1
unnamed: D1.1 (RK), R8.1
USB_D+: U4.4 (I/O2), U6.32 (PA11)
USB_D-: U4.6 (I/O1), U6.31 (PA10)
VBUS: C11.1, P1.A4 (VBUS), P1.A9 (VBUS), P1.B4 (VBUS), P1.B9 (VBUS), U3.3 (VI), U4.5 (VBUS)

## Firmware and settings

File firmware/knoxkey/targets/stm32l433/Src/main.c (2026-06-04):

/**
 ******************************************************************************
 * @file           : main.c
 * @brief          : Main program body — Knox Key stm32l433 target
 ******************************************************************************
 *
 * Knox Key hardware:
 *   MCU:       stm32l433CBU6 (Cortex-M0, 48 MHz, 128KB flash, 16KB RAM)
 *   Crystal:   8 MHz HSE
 *   USB:       USB 2.0 Full-Speed (USB FS peripheral with integrated PHY)
 *   Security:  ATECC608B via I2C (PB6/PB7)
 *   LED:       PA0 (status LED, active high)
 *   Button:    PA1 (user presence button)
 *   LDO:      MCP1700-3.3V
 *
 ******************************************************************************
 */

#include "main.h"
#include "app.h"

/* Private variables ---------------------------------------------------------*/
volatile Button_Event CurrentButtonEvent = BUTTON_EVENT_NONE;
static uint32_t button_press_start = 0;
static uint32_t last_button_release = 0;
static uint8_t click_count = 0;
static bool button_is_pressed = false;
TIM_HandleTypeDef hTIM2;

/* Private function prototypes -----------------------------------------------*/
void SystemClock_Config(void);
static void MX_GPIO_Init(void);
static void MX_I2C1_Init(void);

int Debug_UART_Get_Byte(void) {
	return -1;
}

static Status_LED_Mode current_led_mode = STATUS_LED_MODE_OFF;
static uint32_t led_animation_start = 0;
static Status_LED_Mode previous_led_mode = STATUS_LED_MODE_OFF;

void Status_LED_Set_Mode(Status_LED_Mode mode) {
    if (mode == STATUS_LED_MODE_SUCCESS || mode == STATUS_LED_MODE_ERROR || mode == STATUS_LED_MODE_WINK) {
        if (current_led_mode != mode) {
            previous_led_mode = current_led_mode;
        }
        led_animation_start = HAL_GetTick();
    }
	current_led_mode = mode;
	if (mode == STATUS_LED_MODE_OFF) {
		HAL_GPIO_WritePin(LED_GPIO_Port, LED_R_Pin | LED_G_Pin | LED_B_Pin, GPIO_PIN_RESET);
	} else if (mode == STATUS_LED_MODE_ON) {
		HAL_GPIO_WritePin(LED_GPIO_Port, LED_R_Pin | LED_G_Pin | LED_B_Pin, GPIO_PIN_RESET);
		HAL_GPIO_WritePin(LED_GPIO_Port, LED_G_Pin, GPIO_PIN_SET); /* Solid Green */
	}
}

void Status_LED_Update(void) {
	uint32_t tick = HAL_GetTick();
	if (current_led_mode == STATUS_LED_MODE_BLINKING_NORMAL) {
		if ((tick % 1000) < 500) {
			HAL_GPIO_WritePin(LED_GPIO_Port, LED_R_Pin | LED_G_Pin, GPIO_PIN_RESET);
			HAL_GPIO_WritePin(LED_GPIO_Port, LED_B_Pin, GPIO_PIN_SET); /* Blue blink */
		} else {
			HAL_GPIO_WritePin(LED_GPIO_Port, LED_B_Pin, GPIO_PIN_RESET);
		}
	} else if (current_led_mode == STATUS_LED_MODE_BLINKING_SPECIAL) {
		if ((tick % 100) < 50) {
			HAL_GPIO_WritePin(LED_GPIO_Port, LED_B_Pin, GPIO_PIN_RESET);
			HAL_GPIO_WritePin(LED_GPIO_Port, LED_R_Pin | LED_G_Pin, GPIO_PIN_SET); /* Yellow blink */
		} else {
			HAL_GPIO_WritePin(LED_GPIO_Port, LED_R_Pin | LED_G_Pin, GPIO_PIN_RESET);
		}
	} else if (current_led_mode == STATUS_LED_MODE_SUCCESS) {
        if (tick - led_animation_start < 1000) {
            HAL_GPIO_WritePin(LED_GPIO_Port, LED_R_Pin | LED_B_Pin, GPIO_PIN_RESET);
            HAL_GPIO_WritePin(LED_GPIO_Port, LED_G_Pin, GPIO_PIN_SET); /* Solid Green */
        } else {
            Status_LED_Set_Mode(previous_led_mode);
        }
    } else if (current_led_mode == STATUS_LED_MODE_ERROR) {
        if (tick - led_animation_start < 1000) {
            HAL_GPIO_WritePin(LED_GPIO_Port, LED_G_Pin | LED_B_Pin, GPIO_PIN_RESET);
            HAL_GPIO_WritePin(LED_GPIO_Port, LED_R_Pin, GPIO_PIN_SET); /* Solid Red */
        } else {
            Status_LED_Set_Mode(previous_led_mode);
        }
    } else if (current_led_mode == STATUS_LED_MODE_WINK) {
        if (tick - led_animation_start < 2000) {
            if ((tick % 200) < 100) {
                HAL_GPIO_WritePin(LED_GPIO_Port, LED_R_Pin | LED_G_Pin | LED_B_Pin, GPIO_PIN_SET); /* White wink */
            } else {
                HAL_GPIO_WritePin(LED_GPIO_Port, LED_R_Pin | LED_G_Pin | LED_B_Pin, GPIO_PIN_RESET);
            }
        } else {
            Status_LED_Set_Mode(previous_led_mode);
        }
    }
}

int main(void) {
	HAL_Init();
	SystemClock_Config();
	MX_GPIO_Init();
	MX_I2C1_Init();

	app_run();
}

/**
 * @brief System Clock Configuration
 *        HSE 8 MHz → PLL → 48 MHz SYSCLK
 *        HSI48 → USB 48 MHz clock
 * @retval None
 */
void SystemClock_Config(void) {
	RCC_OscInitTypeDef RCC_OscInitStruct = {0};
	RCC_ClkInitTypeDef RCC_ClkInitStruct = {0};
	RCC_PeriphCLKInitTypeDef PeriphClkInit = {0};

	HAL_PWREx_ControlVoltageScaling(PWR_REGULATOR_VOLTAGE_SCALE1);

	RCC_OscInitStruct.OscillatorType = RCC_OSCILLATORTYPE_HSI48 | RCC_OSCILLATORTYPE_MSI;
	RCC_OscInitStruct.HSI48State = RCC_HSI48_ON;
	RCC_OscInitStruct.MSIState = RCC_MSI_ON;
	RCC_OscInitStruct.MSICalibrationValue = 0;
	RCC_OscInitStruct.MSIClockRange = RCC_MSIRANGE_11; /* 48 MHz */
	RCC_OscInitStruct.PLL.PLLState = RCC_PLL_NONE;
	if (HAL_RCC_OscConfig(&RCC_OscInitStruct) != HAL_OK) {
		Error_Handler();
	}

	RCC_ClkInitStruct.ClockType = RCC_CLOCKTYPE_HCLK | RCC_CLOCKTYPE_SYSCLK | RCC_CLOCKTYPE_PCLK1 | RCC_CLOCKTYPE_PCLK2;
	RCC_ClkInitStruct.SYSCLKSource = RCC_SYSCLKSOURCE_MSI;
	RCC_ClkInitStruct.AHBCLKDivider = RCC_SYSCLK_DIV1;
	RCC_ClkInitStruct.APB1CLKDivider = RCC_HCLK_DIV1;
	RCC_ClkInitStruct.APB2CLKDivider = RCC_HCLK_DIV1;
	if (HAL_RCC_ClockConfig(&RCC_ClkInitStruct, FLASH_LATENCY_2) != HAL_OK) {
		Error_Handler();
	}

	PeriphClkInit.PeriphClockSelection = RCC_PERIPHCLK_USB;
	PeriphClkInit.UsbClockSelection = RCC_USBCLKSOURCE_HSI48;
	if (HAL_RCCEx_PeriphCLKConfig(&PeriphClkInit) != HAL_OK) {
		Error_Handler();
	}
}

I2C_HandleTypeDef hi2c1;

static void MX_I2C1_Init(void) {
	hi2c1.Instance = I2C1;
	hi2c1.Init.Timing = 0x10909CEC; /* 100kHz at 48MHz SYSCLK (from CubeMX) */
	hi2c1.Init.OwnAddress1 = 0;
	hi2c1.Init.AddressingMode = I2C_ADDRESSINGMODE_7BIT;
	hi2c1.Init.DualAddressMode = I2C_DUALADDRESS_DISABLE;
	hi2c1.Init.OwnAddress2 = 0;
	hi2c1.Init.OwnAddress2Masks = I2C_OA2_NOMASK;
	hi2c1.Init.GeneralCallMode = I2C_GENERALCALL_DISABLE;
	hi2c1.Init.NoStretchMode = I2C_NOSTRETCH_DISABLE;
	if (HAL_I2C_Init(&hi2c1) != HAL_OK) {
		Error_Handler();
	}
	if (HAL_I2CEx_ConfigAnalogFilter(&hi2c1, I2C_ANALOGFILTER_ENABLE) != HAL_OK) {
		Error_Handler();
	}
	if (HAL_I2CEx_ConfigDigitalFilter(&hi2c1, 0) != HAL_OK) {
		Error_Handler();
	}
}

void HAL_I2C_MspInit(I2C_HandleTypeDef* hi2c) {
	GPIO_InitTypeDef GPIO_InitStruct = {0};
	if(hi2c->Instance==I2C1) {
		__HAL_RCC_GPIOB_CLK_ENABLE();
		/**I2C1 GPIO Configuration
		PB6     ------> I2C1_SCL
		PB7     ------> I2C1_SDA
		*/
		GPIO_InitStruct.Pin = ATECC_SCL_Pin|ATECC_SDA_Pin;
		GPIO_InitStruct.Mode = GPIO_MODE_AF_OD;
		GPIO_InitStruct.Pull = GPIO_NOPULL;
		GPIO_InitStruct.Speed = GPIO_SPEED_FREQ_VERY_HIGH;
		GPIO_InitStruct.Alternate = GPIO_AF4_I2C1;
		HAL_GPIO_Init(GPIOB, &GPIO_InitStruct);
		__HAL_RCC_I2C1_CLK_ENABLE();
	}
}

/**
 * @brief GPIO Initialization Function
 */
static void MX_GPIO_Init(void) {
	GPIO_InitTypeDef GPIO_InitStruct = {0};

	__HAL_RCC_GPIOA_CLK_ENABLE();
	__HAL_RCC_GPIOB_CLK_ENABLE();
	__HAL_RCC_GPIOH_CLK_ENABLE();

	/* LED pins */
	HAL_GPIO_WritePin(LED_GPIO_Port, LED_R_Pin | LED_G_Pin | LED_B_Pin, GPIO_PIN_RESET);
	GPIO_InitStruct.Pin = LED_R_Pin | LED_G_Pin | LED_B_Pin;
	GPIO_InitStruct.Mode = GPIO_MODE_OUTPUT_PP;
	GPIO_InitStruct.Pull = GPIO_NOPULL;
	GPIO_InitStruct.Speed = GPIO_SPEED_FREQ_LOW;
	HAL_GPIO_Init(LED_GPIO_Port, &GPIO_InitStruct);

	/* User button — PA1, external interrupt on rising edge */
	GPIO_InitStruct.Pin = USER_BTN_Pin;
	GPIO_InitStruct.Mode = GPIO_MODE_IT_RISING;
	GPIO_InitStruct.Pull = GPIO_PULLDOWN;
	HAL_GPIO_Init(USER_BTN_GPIO_Port, &GPIO_InitStruct);

	/* Enable EXTI interrupt for the button */
	HAL_NVIC_SetPriority(EXTI1_IRQn, 2, 0);
	HAL_NVIC_EnableIRQ(EXTI1_IRQn);
}

/**
 * @brief  This function is executed in case of error occurrence.
 */
void Error_Handler(void) {
	__disable_irq();
	while (1) {
	}
}

#ifdef USE_FULL_ASSERT
void assert_failed(uint8_t *file, uint32_t line) {
	(void)file;
	(void)line;
}
#endif

void Button_Update(void) {
    uint32_t tick = HAL_GetTick();
    bool raw_pressed = (HAL_GPIO_ReadPin(USER_BTN_GPIO_Port, USER_BTN_Pin) == GPIO_PIN_SET);

    if (raw_pressed && !button_is_pressed) {
        if (tick - last_button_release > 20) { // Debounce 20ms
            button_is_pressed = true;
            button_press_start = tick;
        }
    } else if (!raw_pressed && button_is_pressed) {
        if (tick - button_press_start > 20) { // Debounce 20ms
            button_is_pressed = false;
            last_button_release = tick;
            uint32_t duration = tick - button_press_start;
            
            if (duration >= 1000) {
                CurrentButtonEvent = BUTTON_EVENT_LONG_PRESS;
                click_count = 0;
            } else {
                click_count++;
            }
        }
    }

    if (!button_is_pressed && click_count > 0 && (tick - last_button_release > 300)) {
        if (click_count == 1) {
            CurrentButtonEvent = BUTTON_EVENT_SINGLE_CLICK;
        } else if (click_count >= 2) {
            CurrentButtonEvent = BUTTON_EVENT_DOUBLE_CLICK;
        }
        click_count = 0;
    }
}

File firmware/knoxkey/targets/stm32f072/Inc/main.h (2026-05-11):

/**
 ******************************************************************************
 * @file           : main.h
 * @brief          : Header for main.c file.
 *                   Knox Key STM32F072 target.
 ******************************************************************************
 */

#ifndef __MAIN_H
#define __MAIN_H

#ifdef __cplusplus
extern "C" {
#endif

/* Includes ------------------------------------------------------------------*/
#include "stm32f0xx_hal.h"
#include <stdio.h>

/* Exported types ------------------------------------------------------------*/

extern __IO uint32_t ButtonState;

#define BUTTON_RELEASED  0
#define BUTTON_PRESSED   1

/* Exported functions prototypes ---------------------------------------------*/
void Error_Handler(void);

int Debug_UART_Get_Byte(void);

typedef enum Status_LED_Mode {
	STATUS_LED_MODE_OFF = 0,
	STATUS_LED_MODE_ON = 1,
	STATUS_LED_MODE_BLINKING_NORMAL = 2,
	STATUS_LED_MODE_BLINKING_SPECIAL = 3,
} Status_LED_Mode;

void Status_LED_Set_Mode(Status_LED_Mode mode);

void HAL_TIM_MspPostInit(TIM_HandleTypeDef *htim);

/* Private defines -----------------------------------------------------------*/
/* Knox Key board pin assignments (from schematic) */

/* Status LED - PA0 (active high, optional replace with RGB) */
#define STATUS_LED_Pin        GPIO_PIN_0
#define STATUS_LED_GPIO_Port  GPIOA

/* User button - PA1 */
#define USER_BTN_Pin          GPIO_PIN_1
#define USER_BTN_GPIO_Port    GPIOA

/* ATECC608B I2C - PB6 (SCL), PB7 (SDA) */
#define ATECC_SCL_Pin         GPIO_PIN_6
#define ATECC_SCL_GPIO_Port   GPIOB
#define ATECC_SDA_Pin         GPIO_PIN_7
#define ATECC_SDA_GPIO_Port   GPIOB

/* USB D+ / D- are on PA11 / PA12 (handled by USB peripheral) */

/* SWD debug - PA13 (SWDIO), PA14 (SWCLK) */
#define SWDIO_Pin             GPIO_PIN_13
#define SWDIO_GPIO_Port       GPIOA
#define SWCLK_Pin             GPIO_PIN_14
#define SWCLK_GPIO_Port       GPIOA

#ifdef __cplusplus
}
#endif

#endif /* __MAIN_H */

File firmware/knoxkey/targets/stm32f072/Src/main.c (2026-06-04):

/**
 ******************************************************************************
 * @file           : main.c
 * @brief          : Main program body — Knox Key STM32F072 target
 ******************************************************************************
 *
 * Knox Key hardware:
 *   MCU:       STM32F072CBU6 (Cortex-M0, 48 MHz, 128KB flash, 16KB RAM)
 *   Crystal:   8 MHz HSE
 *   USB:       USB 2.0 Full-Speed (USB FS peripheral with integrated PHY)
 *   Security:  ATECC608B via I2C (PB6/PB7)
 *   LED:       PA0 (status LED, active high)
 *   Button:    PA1 (user presence button)
 *   LDO:      MCP1700-3.3V
 *
 ******************************************************************************
 */

#include "main.h"
#include "app.h"

/* Private variables ---------------------------------------------------------*/
__IO uint32_t ButtonState = BUTTON_RELEASED;
TIM_HandleTypeDef htim3;

/* Private function prototypes -----------------------------------------------*/
void SystemClock_Config(void);
static void MX_GPIO_Init(void);
static void MX_TIM3_Init(void);

/* Debug UART stub — Knox Key has no dedicated debug UART in the minimal design.
   When needed, SWO or semihosting can be used instead. */
int Debug_UART_Get_Byte(void) {
	return -1;
}

void Status_LED_Set_Mode(Status_LED_Mode mode) {
	switch (mode) {
		case STATUS_LED_MODE_OFF:
			/* Force output low */
			HAL_TIM_PWM_Stop(&htim3, TIM_CHANNEL_1);
			HAL_GPIO_WritePin(STATUS_LED_GPIO_Port, STATUS_LED_Pin, GPIO_PIN_RESET);
			break;
		case STATUS_LED_MODE_ON:
			/* Force output high */
			HAL_TIM_PWM_Stop(&htim3, TIM_CHANNEL_1);
			HAL_GPIO_WritePin(STATUS_LED_GPIO_Port, STATUS_LED_Pin, GPIO_PIN_SET);
			break;
		case STATUS_LED_MODE_BLINKING_NORMAL:
			/* ~1 Hz blink via PWM (50% duty, period = 48M / 48000 = 1000 ticks at prescaler giving 1kHz) */
			htim3.Instance->ARR = 999;
			htim3.Instance->CCR1 = 500;
			htim3.Instance->PSC = 47999; /* 48 MHz / 48000 = 1 kHz tick */
			HAL_TIM_PWM_Start(&htim3, TIM_CHANNEL_1);
			break;
		case STATUS_LED_MODE_BLINKING_SPECIAL:
			/* Fast blink ~10 Hz */
			htim3.Instance->ARR = 99;
			htim3.Instance->CCR1 = 50;
			htim3.Instance->PSC = 47999; /* 48 MHz / 48000 = 1 kHz tick */
			HAL_TIM_PWM_Start(&htim3, TIM_CHANNEL_1);
			break;
	}
}

/**
 * @brief  The application entry point.
 * @retval int
 */
int main(void) {

	HAL_Init();
	SystemClock_Config();
	MX_GPIO_Init();
	MX_TIM3_Init();

	/* app_run never returns */
	app_run();
}

/**
 * @brief System Clock Configuration
 *        HSE 8 MHz → PLL → 48 MHz SYSCLK
 *        HSI48 → USB 48 MHz clock
 * @retval None
 */
void SystemClock_Config(void) {
	RCC_OscInitTypeDef RCC_OscInitStruct = {0};
	RCC_ClkInitTypeDef RCC_ClkInitStruct = {0};
	RCC_PeriphCLKInitTypeDef PeriphClkInit = {0};

	/* Enable HSE (8 MHz crystal) and PLL (8 MHz / 1 * 6 = 48 MHz) */
	RCC_OscInitStruct.OscillatorType = RCC_OSCILLATORTYPE_HSE | RCC_OSCILLATORTYPE_HSI48;
	RCC_OscInitStruct.HSEState = RCC_HSE_ON;
	RCC_OscInitStruct.HSI48State = RCC_HSI48_ON;
	RCC_OscInitStruct.PLL.PLLState = RCC_PLL_ON;
	RCC_OscInitStruct.PLL.PLLSource = RCC_PLLSOURCE_HSE;
	RCC_OscInitStruct.PLL.PLLMUL = RCC_PLL_MUL6;
	RCC_OscInitStruct.PLL.PREDIV = RCC_PREDIV_DIV1;
	if (HAL_RCC_OscConfig(&RCC_OscInitStruct) != HAL_OK) {
		Error_Handler();
	}

	/* SYSCLK = PLLCLK = 48 MHz, HCLK = 48 MHz, PCLK1 = 48 MHz */
	RCC_ClkInitStruct.ClockType = RCC_CLOCKTYPE_HCLK | RCC_CLOCKTYPE_SYSCLK | RCC_CLOCKTYPE_PCLK1;
	RCC_ClkInitStruct.SYSCLKSource = RCC_SYSCLKSOURCE_PLLCLK;
	RCC_ClkInitStruct.AHBCLKDivider = RCC_SYSCLK_DIV1;
	RCC_ClkInitStruct.APB1CLKDivider = RCC_HCLK_DIV1;
	if (HAL_RCC_ClockConfig(&RCC_ClkInitStruct, FLASH_LATENCY_1) != HAL_OK) {
		Error_Handler();
	}

	/* USB clock from HSI48 (dedicated 48 MHz oscillator) */
	PeriphClkInit.PeriphClockSelection = RCC_PERIPHCLK_USB;
	PeriphClkInit.UsbClockSelection = RCC_USBCLKSOURCE_HSI48;
	if (HAL_RCCEx_PeriphCLKConfig(&PeriphClkInit) != HAL_OK) {
		Error_Handler();
	}
}

/**
 * @brief TIM3 Initialization Function — used for LED PWM on PA0 (TIM3_CH1)
 */
static void MX_TIM3_Init(void) {
	TIM_OC_InitTypeDef sConfigOC = {0};

	__HAL_RCC_TIM3_CLK_ENABLE();

	htim3.Instance = TIM3;
	htim3.Init.Prescaler = 47999; /* 48 MHz / 48000 = 1 kHz */
	htim3.Init.CounterMode = TIM_COUNTERMODE_UP;
	htim3.Init.Period = 999;      /* 1 kHz / 1000 = 1 Hz */
	htim3.Init.ClockDivision = TIM_CLOCKDIVISION_DIV1;
	htim3.Init.AutoReloadPreload = TIM_AUTORELOAD_PRELOAD_DISABLE;
	if (HAL_TIM_PWM_Init(&htim3) != HAL_OK) {
		Error_Handler();
	}

	sConfigOC.OCMode = TIM_OCMODE_PWM1;
	sConfigOC.Pulse = 0;
	sConfigOC.OCPolarity = TIM_OCPOLARITY_HIGH;
	sConfigOC.OCFastMode = TIM_OCFAST_DISABLE;
	if (HAL_TIM_PWM_ConfigChannel(&htim3, &sConfigOC, TIM_CHANNEL_1) != HAL_OK) {
		Error_Handler();
	}

	/* TIM3 CH1 GPIO — PA0 AF1 (TIM3_CH1) */
	HAL_TIM_MspPostInit(&htim3);
}

void HAL_TIM_MspPostInit(TIM_HandleTypeDef *htim) {
	GPIO_InitTypeDef GPIO_InitStruct = {0};
	if (htim->Instance == TIM3) {
		__HAL_RCC_GPIOA_CLK_ENABLE();
		/* PA0 — TIM3_CH1, AF1 */
		GPIO_InitStruct.Pin = STATUS_LED_Pin;
		GPIO_InitStruct.Mode = GPIO_MODE_AF_PP;
		GPIO_InitStruct.Pull = GPIO_NOPULL;
		GPIO_InitStruct.Speed = GPIO_SPEED_FREQ_LOW;
		GPIO_InitStruct.Alternate = GPIO_AF1_TIM3;
		HAL_GPIO_Init(STATUS_LED_GPIO_Port, &GPIO_InitStruct);
	}
}

/**
 * @brief GPIO Initialization Function
 */
static void MX_GPIO_Init(void) {
	GPIO_InitTypeDef GPIO_InitStruct = {0};

	__HAL_RCC_GPIOA_CLK_ENABLE();
	__HAL_RCC_GPIOB_CLK_ENABLE();
	__HAL_RCC_GPIOF_CLK_ENABLE();

	/* LED pin — start as push-pull output (will be switched to AF when PWM starts) */
	HAL_GPIO_WritePin(STATUS_LED_GPIO_Port, STATUS_LED_Pin, GPIO_PIN_RESET);
	GPIO_InitStruct.Pin = STATUS_LED_Pin;
	GPIO_InitStruct.Mode = GPIO_MODE_OUTPUT_PP;
	GPIO_InitStruct.Pull = GPIO_NOPULL;
	GPIO_InitStruct.Speed = GPIO_SPEED_FREQ_LOW;
	HAL_GPIO_Init(STATUS_LED_GPIO_Port, &GPIO_InitStruct);

	/* User button — PA1, external interrupt on rising edge */
	GPIO_InitStruct.Pin = USER_BTN_Pin;
	GPIO_InitStruct.Mode = GPIO_MODE_IT_RISING;
	GPIO_InitStruct.Pull = GPIO_PULLDOWN;
	HAL_GPIO_Init(USER_BTN_GPIO_Port, &GPIO_InitStruct);

	/* Enable EXTI interrupt for the button */
	HAL_NVIC_SetPriority(EXTI0_1_IRQn, 2, 0);
	HAL_NVIC_EnableIRQ(EXTI0_1_IRQn);
}

/**
 * @brief  This function is executed in case of error occurrence.
 */
void Error_Handler(void) {
	__disable_irq();
	while (1) {
	}
}

#ifdef USE_FULL_ASSERT
void assert_failed(uint8_t *file, uint32_t line) {
	(void)file;
	(void)line;
}
#endif

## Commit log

2026-05-02 Initial commit of Knox Key hardware files
    [BOM.csv, BOM_suggested.csv, Knox Key Kicad.kicad_pcb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]
2026-05-02 refactor: clean repository and remove kryptonite references
    - Organize directories: manufacturing-kryptonite/ → manufacturing/, img-kryptonite/ → design-images/
    - Rename backup directories: backup-kryptonite-* → backup-*
    - Rename DESIGN updates: README-kryptonite-update.md → DESIGN-UPDATES.md
    - Update all gerber files and manufacturing outputs: kryptonite-* → knox-key-*
    - Rename position file: kryptonite-pos.csv → component-positions.csv
    - Add comprehensive .gitignore for KiCad projects
    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
    [BOM.csv, Knox Key Kicad.kicad_pcb, Knox Key Kicad.kicad_sch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]
2026-05-08 Ignore KiCad backups and caches
    [Knox Key Kicad.kicad_pcb, Knox Key Kicad.kicad_sch]
2026-05-08 Reorganize hardware layout
    [Knox Key Kicad.kicad_pcb, Knox Key Kicad.kicad_sch]
2026-05-11 Update README: Embed new design renders, update to STM32L433, add ATECC608B FIDO details, and remove emojis
    [Knox Key Kicad.kicad_pcb, Knox Key Kicad.kicad_sch]
2026-05-11 Add full firmware port to repository
    [doxygen.cfg, st_nucleo_h5.cfg]
2026-05-11 Rename firmware from lionkey to knoxkey globally and add specific firmware README
    [doxygen.cfg, st_nucleo_h5.cfg]
2026-05-28 docs: add project journal, map screenshots, and update firmware code/configs
    [Knox Key Kicad.kicad_pcb]
2026-05-28 feat: add JLCPCB production BOM, placement, and fab archive
    [bom.csv, designators.csv, positions.csv]
2026-06-04 refactor: combine production and manufacturing directories into manufacturing/
    [BOM.csv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]
2026-08-08 Add BOM.csv/BOM.md, remove duplicate files
    - Add BOM.csv and BOM.md at repo root (17 line items, 29 components, LCSC part numbers) per Hack Club submission feedback.
    - Remove hardware/, a stale duplicate copy of the KiCad project files that predates and is superseded by the root .kicad_pcb/.kicad_pro/.kicad_sch (which the README instructs opening), plus an orphan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
    - Remove duplicate design-image renders (3D-Front.png, 3D-Back.png, PCB.png, schematic.png, Schematic/Schamatic.png) that were byte-identical or superseded copies of design-images/PCB/ and design-ima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
    - Update R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
    [BOM.csv, Knox Key Kicad.kicad_pcb, Knox Key Kicad.kicad_sch]
2026-08-08 Embed BOM table in README
    Per reviewer feedback: add the bill of materials as a markdown table directly in README.md, not just linked out to BOM.md/BOM.csv.
